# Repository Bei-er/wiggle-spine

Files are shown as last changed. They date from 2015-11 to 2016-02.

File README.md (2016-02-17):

wiggleport

This is the Wiggle **Spine**, an open hardware design for [Wiggleport](http://wiggleport.org)'s power and data hub.

* Each "spine" board has a 480 Mbit/s USB 2.0 uplink and 7 connectors for **modules**.
* Drive up to 14 speakers at 48/96 kHz per channel from one USB port.
* Connect sensors and lights, sync them perfectly with sound and each other.
* Use it to create objects and environments that are perfectly synchronized with immersive sound and vibration.
* Connect other audio-frequency devices like vibration transducers, LED strobes, and modular synthesizers.
* Use all the processing power in your PC, or run from an embedded Linux board like the Raspberry Pi 2.
* Gain accurate control of I/O timing from high-level languages like Javascript.

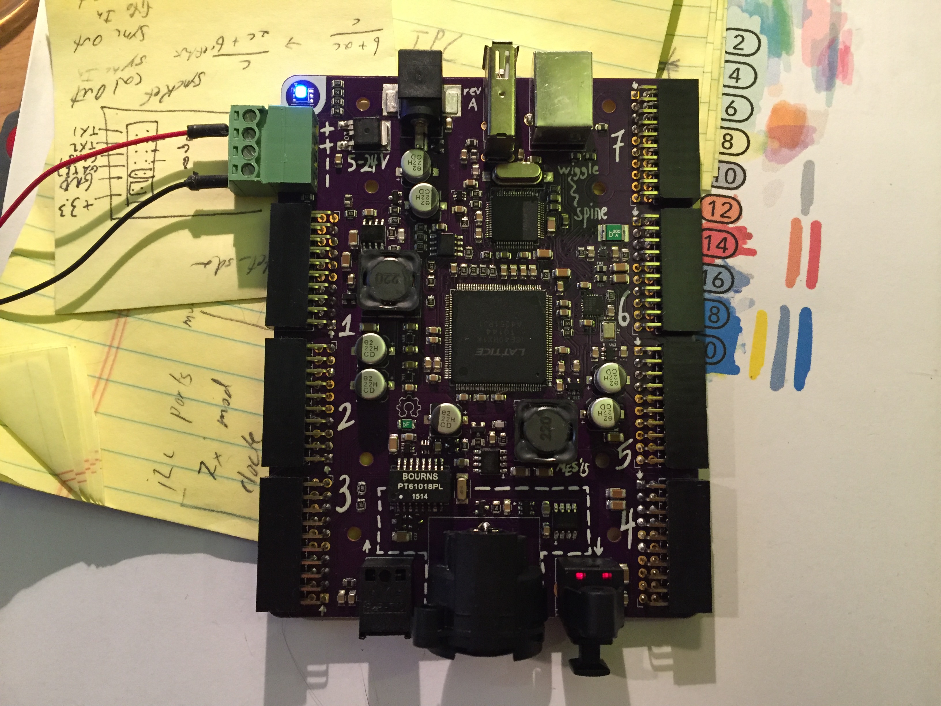
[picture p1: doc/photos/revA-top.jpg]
Wiggle Spine prototype photo


Scale it up or down
-------------------

* Multiple spines can be synchronized with cheap TOSLINK-style optical cables
  * USB links can go to the same or different computers, depending on how much processing power you need
  * Everyone shares a common audio clock and timestamps

* The spine also has a built-in DMX output so it's easy to add inexpensive lights and effects to your project
  * The output has galvanic isolation, to prevent grounding problems or audio hum
  * The DMX outputs can of course synchronize with all other inputs and outputs

* Wiggleport distributes power too, not just data
  * Flexible power input, 5 to 24 volts 
  * Lots of power, over 300 watts total
  * Each module has 5V, 3.3V, and 5-24V available
  * There's also a 5V power output for running a Raspberry Pi or other small computer
  * Also there's a watchdog timer, to reboot the computer if it stops running for any reason

Internals
---------

Wiggleport is an open source hardware design optimized for simple and straightforward real-time performance. It's based around an FTDI FT2232H high-speed USB FIFO interface, combined with a precision clock synthesizer and a tiny FPGA for glue logic. It stays simple and inexpensive by doing much of the work in software, relying on the powerful CPUs available on even small embedded Linux boards now.

Wiggleport isn't really a sound card, even though you can use it as one. It has its own APIs for C++, MIDI, and Javascript. You can write code for precisely timed multichannel sound installations on your laptop on Mac OS, for example, and run the same code on a Raspberry Pi later on.

Going even deeper, Wiggleport is really kind of a construction kit for hardware and drivers that stream signals in real-time. This reconfigurability is what lets Wiggleport automatically configure the various add-on modules, but you can also use this core directly to create your own hardware, with or without including an FPGA.

**Coming soon**... development is happening here now! You can follow the progress at [wiggleport.org](http://wiggleport.org).

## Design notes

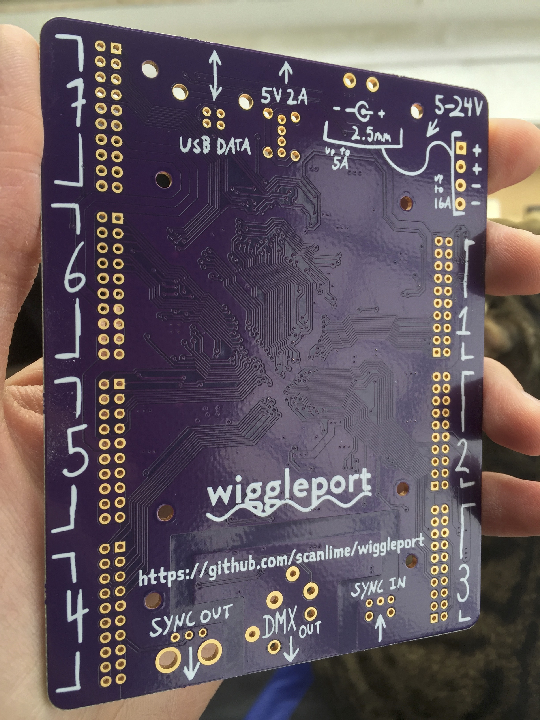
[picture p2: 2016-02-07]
doc/photos/revA-bottom.jpg

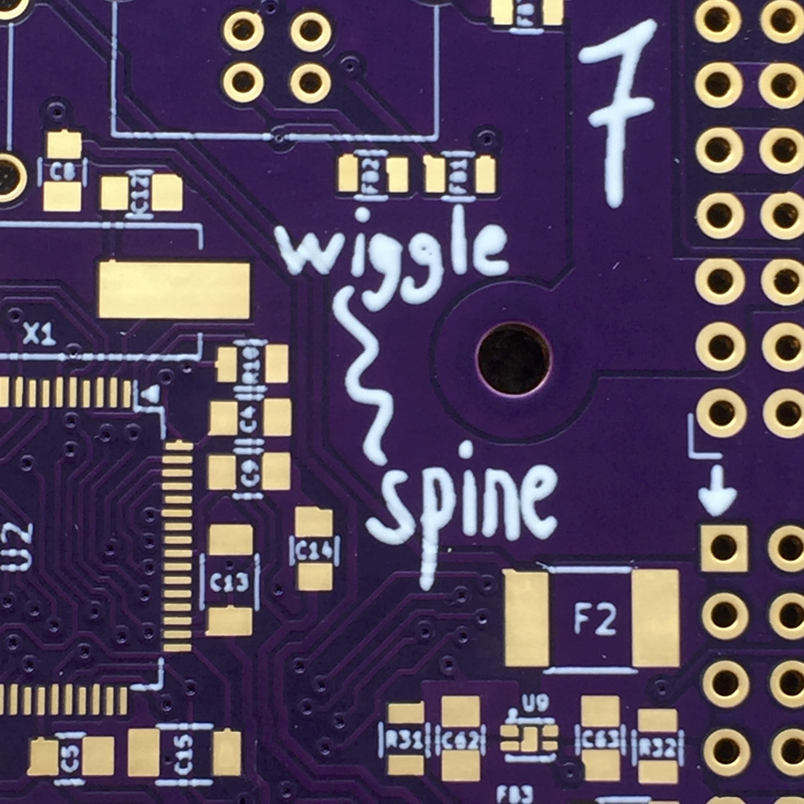
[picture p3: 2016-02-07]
doc/photos/revA-spine-closeup.jpg

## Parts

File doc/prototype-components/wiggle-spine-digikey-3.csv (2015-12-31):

Index | Quantity | Part Number | Description | Customer Reference | Available Quantity | Backorder Quantity | Unit Price USD | Extended Price USD
1 | 50 | 1276-6370-1-ND | FERRITE CHIP 30 OHM 6000MA 0805 |  | 50 | 0 | 0.05640 | 2.82
2 | 10 | 490-7989-1-ND | CAP CER 1000PF 250VAC SL 1808 |  | 10 | 0 | 0.71700 | 7.17
3 | 50 | 493-6180-1-ND | CAP ALUM 22UF 20% 50V SMD |  | 50 | 0 | 0.24320 | 12.16
4 | 10 | 497-3735-1-ND | IC TXRX 5V RS485/422 ESD 8-SOIC |  | 10 | 0 | 0.78700 | 7.87
5 | 25 | 507-1797-1-ND | PTC RESTTBLE 0.20A 30V CHIP 1206 |  | 25 | 0 | 0.09920 | 2.48
6 | 100 | 568-5818-1-ND | MOSFET N-CH 60V 0.36A SOT-23 |  | 100 | 0 | 0.07000 | 7.00
7 | 20 | AP2204K-5.0TRG1DICT-ND | IC REG LDO 5V 0.15A SOT25 |  | 20 | 0 | 0.36300 | 7.26
8 | 20 | BAT54A-FDICT-ND | DIODE ARRAY SCHOTTKY 30V SOT23-3 |  | 20 | 0 | 0.17000 | 3.40
9 | 20 | DMN3190LDW-7DICT-ND | MOSFET 2N-CH 30V 1A SOT363 |  | 20 | 0 | 0.33000 | 6.60

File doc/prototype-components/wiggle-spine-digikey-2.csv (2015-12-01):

Index | Quantity | Part Number | Description | Customer Reference | Available Quantity | Backorder Quantity | Unit Price USD | Extended Price USD
1 | 10 | CLY6D-FKC-CK1N1D1BB7D3D3CT-ND | MSMD LED 3 IN 1 PLCC6 |  | 10 | 0 | 0.49000 | 4.90
2 | 100 | RMCF0805JT750RCT-ND | RES SMD 750 OHM 5% 1/8W 0805 |  | 100 | 0 | 0.00880 | 0.88
3 | 100 | RMCF0805JT240RCT-ND | RES SMD 240 OHM 5% 1/8W 0805 |  | 100 | 0 | 0.00880 | 0.88

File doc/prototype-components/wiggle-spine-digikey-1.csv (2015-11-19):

Index | Quantity | Part Number | Description | Customer Reference | Available Quantity | Backorder Quantity | Unit Price USD | Extended Price USD
1 | 2 | FRDM-KE04Z-ND | DEV TOOL FREEDOM KINETIS 40MHZ |  | 2 | 0 | 15.00000 | 30.00
2 | 1 | 296-36490-ND | EVAL MODULE FOR TAS5760XX |  | 1 | 0 | 100.98000 | 100.98
3 | 25 | 1028-1295-1-ND | IC REG BUCK ADJ 3A SYNC 8SOP |  | 25 | 0 | 0.73000 | 18.25
4 | 10 | 1080-1428-ND | TRANSMITTER FBR OPT IR PHOTOLINK |  | 10 | 0 | 0.86600 | 8.66
5 | 10 | 1080-1433-ND | RECEIVER FIBER OPT IR PHOTOLINK |  | 10 | 0 | 1.64700 | 16.47
6 | 100 | 1276-1829-1-ND | CAP CER 20PF 50V NP0 0805 |  | 100 | 0 | 0.02720 | 2.72
7 | 100 | 1276-6342-1-ND | FERRITE CHIP 26 OHM 2000MA 0805 |  | 100 | 0 | 0.02240 | 2.24
8 | 4 | 220-1565-ND | IC FPGA 96 I/O 144TQFP |  | 4 | 0 | 5.71000 | 22.84
9 | 10 | 296-1275-1-ND | IC DIFF BUS TXCVR 8-SOIC |  | 10 | 0 | 0.68000 | 6.80
10 | 4 | 336-2401-5-ND | IC CLK GENERATOR 160MHZ 20QFN |  | 4 | 0 | 2.69000 | 10.76
11 | 100 | 490-10743-1-ND | CAP CER 1UF 50V X5R 0805 |  | 100 | 0 | 0.08360 | 8.36
12 | 100 | 490-10756-1-ND | CAP CER 10UF 50V X5R 1206 |  | 100 | 0 | 0.15300 | 15.30
13 | 100 | 490-1615-1-ND | CAP CER 100PF 50V NP0 0805 |  | 100 | 0 | 0.03910 | 3.91
14 | 250 | 490-9672-1-ND | CAP CER 0.1UF 50V X7R 0805 |  | 250 | 0 | 0.03760 | 9.40
15 | 100 | 490-9741-1-ND | CAP CER 1000PF 50V X7R 0805 |  | 100 | 0 | 0.02860 | 2.86
16 | 4 | 495-4962-1-ND | CAP FILM 1000PF 20% 1.5KVDC RAD |  | 4 | 0 | 0.88000 | 3.52
17 | 10 | 507-1777-1-ND | PTC RESTTBLE 2.0A 8V CHIP 1812 |  | 10 | 0 | 0.16100 | 1.61
18 | 10 | 553-2272-ND | CONN USB TYPE B JACK |  | 10 | 0 | 0.56000 | 5.60
19 | 10 | 568-6542-1-ND | TVS DIODE 5.5VWM 6TSSOP |  | 10 | 0 | 0.34600 | 3.46
20 | 10 | 644-1267-1-ND | CRYSTAL 25.0000MHZ 8PF SMD |  | 10 | 0 | 0.64100 | 6.41
21 | 5 | 732-5932-1-ND | CONN PWR JACK DC RA SMD |  | 5 | 0 | 1.99000 | 9.95
22 | 4 | 768-1024-1-ND | IC USB HS DUAL UART/FIFO 64-LQFP |  | 4 | 0 | 6.71000 | 26.84
23 | 25 | 785-1351-1-ND | MOSFET P-CH 40V 40A TO252 |  | 25 | 0 | 0.40440 | 10.11
24 | 100 | BAT54C-FDICT-ND | DIODE ARRAY SCHOTTKY 30V SOT23-3 |  | 100 | 0 | 0.09430 | 9.43
25 | 10 | CAT93C56VI-GT3OSCT-ND | IC EEPROM 2KBIT 2MHZ 8SOIC |  | 10 | 0 | 0.39000 | 3.90
26 | 10 | ED2991-ND | CONN USB TYPE A R/A VERTICAL |  | 10 | 0 | 0.64200 | 6.42
27 | 25 | IRFML8244TRPBFCT-ND | MOSFET N-CH 25V 5.8A SOT23 |  | 25 | 0 | 0.18160 | 4.54
28 | 20 | MMBZ12VALT1GOSCT-ND | TVS DIODE 8.5VWM 17VC SOT23 |  | 20 | 0 | 0.18800 | 3.76
29 | 25 | NC7WZ14P6XCT-ND | IC INVERTER DUAL SCHMITT SC70-6 |  | 25 | 0 | 0.23200 | 5.80
30 | 100 | RMCF0805FT12K0CT-ND | RES SMD 12K OHM 1% 1/8W 0805 |  | 100 | 0 | 0.01230 | 1.23
31 | 100 | RMCF0805FT16K0CT-ND | RES SMD 16K OHM 1% 1/8W 0805 |  | 100 | 0 | 0.01230 | 1.23
32 | 100 | RMCF0805FT27K0CT-ND | RES SMD 27K OHM 1% 1/8W 0805 |  | 100 | 0 | 0.01230 | 1.23
33 | 100 | RMCF0805FT5K10CT-ND | RES SMD 5.1K OHM 1% 1/8W 0805 |  | 100 | 0 | 0.01230 | 1.23
34 | 100 | RMCF0805JT100KCT-ND | RES SMD 100K OHM 5% 1/8W 0805 |  | 100 | 0 | 0.00880 | 0.88
35 | 100 | RMCF0805JT10K0CT-ND | RES SMD 10K OHM 5% 1/8W 0805 |  | 100 | 0 | 0.00880 | 0.88
36 | 100 | RMCF0805JT10R0CT-ND | RES SMD 10 OHM 5% 1/8W 0805 |  | 100 | 0 | 0.00880 | 0.88
37 | 100 | RMCF0805JT150RCT-ND | RES SMD 150 OHM 5% 1/8W 0805 |  | 100 | 0 | 0.00880 | 0.88
38 | 100 | RMCF0805JT1M00CT-ND | RES SMD 1M OHM 5% 1/8W 0805 |  | 100 | 0 | 0.00880 | 0.88
39 | 100 | RMCF0805JT2K20CT-ND | RES SMD 2.2K OHM 5% 1/8W 0805 |  | 100 | 0 | 0.00880 | 0.88
40 | 100 | RMCF0805JT4K70CT-ND | RES SMD 4.7K OHM 5% 1/8W 0805 |  | 100 | 0 | 0.00880 | 0.88
41 | 20 | SIP32408DNP-T1-GE4CT-ND | IC LOAD SWITCH 4TDFN |  | 20 | 0 | 0.38700 | 7.74
42 | 25 | SRR1280-220MCT-ND | FIXED IND 22UH 4.3A 38.6 MOHM |  | 25 | 0 | 0.86800 | 21.70
43 | 25 | TCR2EF12LM(CTCT-ND | IC REG LDO 1.2V 0.2A SMV |  | 25 | 0 | 0.21640 | 5.41
44 | 25 | TCR2EF25LM(CTCT-ND | IC REG LDO 2.5V 0.2A SMV |  | 25 | 0 | 0.21640 | 5.41
45 | 10 | 535-9067-1-ND | CRYSTAL 12.0000MHZ 18PF SMD |  | 10 | 0 | 0.23700 | 2.37
 |  |  |  |  |  | Subtotal | 414.61
 |  |  |  |  |  | Shipping | unknown
 |  |  |  |  |  | Estimated Sales Tax | 39.39
 |  |  |  |  |  | Total | unknown

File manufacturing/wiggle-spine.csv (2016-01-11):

Reference | Value | Footprint | Datasheet | Vend1 | Vend1Id | RefPrice1k | Mfg1 | Mfg1Id | Safety Rating | Description
CON1 | USB-B | Connect:USB_B | http://productfinder.pulseeng.com/products/datasheets/E8144-B02022-L.PDF | Digikey | 553-2272-ND | 0.28 | Pulse | E8144-B02022-L
FB2 | Ferrite bead | Resistors_SMD:R_0805 | http://www.samsungsem.com/kr/front/downloadcms.do?fileName=S_CIS21J121NE.pdf | Digikey | 1276-6370-1-ND | 0.02383 | Samsung | CIS21P300NE
FB1 | Ferrite bead | Resistors_SMD:R_0805 | http://www.samsungsem.com/kr/front/downloadcms.do?fileName=S_CIS21J121NE.pdf | Digikey | 1276-6370-1-ND | 0.02383 | Samsung | CIS21P300NE
R4 | 4.7k | Resistors_SMD:R_0805 | https://www.seielect.com/Catalog/SEI-RMCF_RMCP.pdf | Digikey | RMCF0805JT4K70CT-ND | 0.0032 | Stackpole | RMCF0805JT4K70
R5 | 10k | Resistors_SMD:R_0805 | http://www.seielect.com/Catalog/SEI-RMCF_RMCP.pdf | Digikey | RMCF0805JT10K0CT-ND | 0.0032 | Stackpole | RMCF0805JT10K0
U2 | FT2232H | Housings_QFP:LQFP-64_10x10mm_Pitch0.5mm | http://www.ftdichip.com/Support/Documents/DataSheets/ICs/DS_FT2232H.pdf | Digikey | 768-1024-1-ND | 3.70 | FTDI | FT2232HL-REEL
R10 | 12k 1% | Resistors_SMD:R_0805 | https://www.seielect.com/Catalog/SEI-RMCF_RMCP.pdf | Digikey | RMCF0805FT12K0TR-ND | 0.0032 | Stackpole | RMCF0805FT12K0
R7 | 4.7k | Resistors_SMD:R_0805 | https://www.seielect.com/Catalog/SEI-RMCF_RMCP.pdf | Digikey | RMCF0805JT4K70CT-ND | 0.0032 | Stackpole | RMCF0805JT4K70
D1 | TVS DIODE 5.5VWM | TO_SOT_Packages_SMD:SC-70-6 | http://www.nxp.com/documents/data_sheet/PRTR5V0U4Y.pdf | Digikey | DRTR5V0U4S-7DICT-ND | 0.12266 | Diodes Inc | DRTR5V0U4S-7
FB3 | Ferrite bead | Resistors_SMD:R_0805 | http://www.samsungsem.com/kr/front/downloadcms.do?fileName=S_CIS21J121NE.pdf | Digikey | 1276-6370-1-ND | 0.02383 | Samsung | CIS21P300NE
U1 | 93C56 | Housings_SOIC:SOIC-8_3.9x4.9mm_Pitch1.27mm | http://www.onsemi.com/pub_link/Collateral/CAT93C56-D.PDF | Digikey | CAT93C56VI-GT3OSCT-ND | 0.14893 | ON Semi | CAT93C56VI-GT3
R1 | 10k | Resistors_SMD:R_0805 | http://www.seielect.com/Catalog/SEI-RMCF_RMCP.pdf | Digikey | RMCF0805JT10K0CT-ND | 0.0032 | Stackpole | RMCF0805JT10K0
R2 | 10k | Resistors_SMD:R_0805 | http://www.seielect.com/Catalog/SEI-RMCF_RMCP.pdf | Digikey | RMCF0805JT10K0CT-ND | 0.0032 | Stackpole | RMCF0805JT10K0
R3 | 10k | Resistors_SMD:R_0805 | http://www.seielect.com/Catalog/SEI-RMCF_RMCP.pdf | Digikey | RMCF0805JT10K0CT-ND | 0.0032 | Stackpole | RMCF0805JT10K0
R6 | 2.2k | Resistors_SMD:R_0805 | http://www.seielect.com/Catalog/SEI-RMCF_RMCP.pdf | Digikey | RMCF0805JT2K20CT-ND | 0.0032 | Stackpole | RMCF0805JT2K20CT
C2 | 0.1uF | Capacitors_SMD:C_0805 | http://psearch.murata.com/capacitor/product/GRM21BR71H104MA01%23.pdf | Digikey | 490-9672-2-ND | 0.01880 | Murata | GRM21BR71H104MA01L
X1 | 12 MHz | Crystals:Crystal_HC49-SD_SMD | http://www.abracon.com/Resonators/abls.pdf | Digikey | 535-10218-1-ND | 0.172 | Abracon | ABLS-12.000MHZ-B4-T
C12 | 20pF | Capacitors_SMD:C_0805 | http://www.samsungsem.com/kr/support/product-search/mlcc/CL21C200JBANNNC.jsp | Digikey | 1276-1829-1-ND | 0.01485 | Samsung | CL21C200JBANNNC
R8 | 10 | Resistors_SMD:R_0805 | http://www.seielect.com/Catalog/SEI-RMCF_RMCP.pdf | Digikey | RMCF0805JT10R0CT-ND | 0.0032 | Stackpole | RMCF0805JT10R0CT
R9 | 10 | Resistors_SMD:R_0805 | http://www.seielect.com/Catalog/SEI-RMCF_RMCP.pdf | Digikey | RMCF0805JT10R0CT-ND | 0.0032 | Stackpole | RMCF0805JT10R0CT
C3 | 0.1uF | Capacitors_SMD:C_0805 | http://psearch.murata.com/capacitor/product/GRM21BR71H104MA01%23.pdf | Digikey | 490-9672-2-ND | 0.01880 | Murata | GRM21BR71H104MA01L
C4 | 0.1uF | Capacitors_SMD:C_0805 | http://psearch.murata.com/capacitor/product/GRM21BR71H104MA01%23.pdf | Digikey | 490-9672-2-ND | 0.01880 | Murata | GRM21BR71H104MA01L
C5 | 0.1uF | Capacitors_SMD:C_0805 | http://psearch.murata.com/capacitor/product/GRM21BR71H104MA01%23.pdf | Digikey | 490-9672-2-ND | 0.01880 | Murata | GRM21BR71H104MA01L
C7 | 0.1uF | Capacitors_SMD:C_0805 | http://psearch.murata.com/capacitor/product/GRM21BR71H104MA01%23.pdf | Digikey | 490-9672-2-ND | 0.01880 | Murata | GRM21BR71H104MA01L
C9 | 0.1uF | Capacitors_SMD:C_0805 | http://psearch.murata.com/capacitor/product/GRM21BR71H104MA01%23.pdf | Digikey | 490-9672-2-ND | 0.01880 | Murata | GRM21BR71H104MA01L
C11 | 0.1uF | Capacitors_SMD:C_0805 | http://psearch.murata.com/capacitor/product/GRM21BR71H104MA01%23.pdf | Digikey | 490-9672-2-ND | 0.01880 | Murata | GRM21BR71H104MA01L
C6 | 0.1uF | Capacitors_SMD:C_0805 | http://psearch.murata.com/capacitor/product/GRM21BR71H104MA01%23.pdf | Digikey | 490-9672-2-ND | 0.01880 | Murata | GRM21BR71H104MA01L
C1 | 0.1uF | Capacitors_SMD:C_0805 | http://psearch.murata.com/capacitor/product/GRM21BR71H104MA01%23.pdf | Digikey | 490-9672-2-ND | 0.01880 | Murata | GRM21BR71H104MA01L
C13 | 10uF | Capacitors_SMD:C_1206 | http://www.murata.com/~/media/webrenewal/support/library/catalog/products/capacitor/mlcc/c02e.ashx | Digikey | 490-10756-2-ND | 0.07429 | Murata | GRM31CR61H106MA12L
C15 | 10uF | Capacitors_SMD:C_1206 | http://www.murata.com/~/media/webrenewal/support/library/catalog/products/capacitor/mlcc/c02e.ashx | Digikey | 490-10756-2-ND | 0.07429 | Murata | GRM31CR61H106MA12L
C8 | 0.1uF | Capacitors_SMD:C_0805 | http://psearch.murata.com/capacitor/product/GRM21BR71H104MA01%23.pdf | Digikey | 490-9672-2-ND | 0.01880 | Murata | GRM21BR71H104MA01L
C10 | 10uF | Capacitors_SMD:C_1206 | http://www.murata.com/~/media/webrenewal/support/library/catalog/products/capacitor/mlcc/c02e.ashx | Digikey | 490-10756-2-ND | 0.07429 | Murata | GRM31CR61H106MA12L
FB4 | Ferrite bead | Resistors_SMD:R_0805 | http://www.samsungsem.com/kr/front/downloadcms.do?fileName=S_CIS21J121NE.pdf | Digikey | 1276-6370-1-ND | 0.02383 | Samsung | CIS21P300NE
C14 | 0.1uF | Capacitors_SMD:C_0805 | http://psearch.murata.com/capacitor/product/GRM21BR71H104MA01%23.pdf | Digikey | 490-9672-2-ND | 0.01880 | Murata | GRM21BR71H104MA01L
C17 | 10uF | Capacitors_SMD:C_1206 | http://www.murata.com/~/media/webrenewal/support/library/catalog/products/capacitor/mlcc/c02e.ashx | Digikey | 490-10756-2-ND | 0.07429 | Murata | GRM31CR61H106MA12L
C16 | 20pF | Capacitors_SMD:C_0805 | http://www.samsungsem.com/kr/support/product-search/mlcc/CL21C200JBANNNC.jsp | Digikey | 1276-1829-1-ND | 0.01485 | Samsung | CL21C200JBANNNC
T1 | 10/100baseT transformer | Housings_SOIC:SOIC-16_7.5x10.3mm_Pitch1.27mm | http://www.mouser.com/ds/2/54/PT61018PEL-336005.pdf | Mouser | 652-PT61018PEL | 0.78 | Bourns | PT61018PEL
C23 | 1nF | Capacitors_SMD:C_0805 | http://search.murata.co.jp/Ceramy/image/img/A01X/G101/ENG/GRM216R71H102KA01-01.pdf | Digikey | 490-9741-1-ND | 0.0156 | Murata | GRM216R71H102KA01D
D2 | BAT54 2x common cathode | TO_SOT_Packages_SMD:SOT-23 | http://www.diodes.com/_files/datasheets/ds11005.pdf | Digikey | BAT54C-FDICT-ND | .03955 | Diodes Inc | BAT54C-7-F
U3 | NC7WZ14 | TO_SOT_Packages_SMD:SC-70-6 | http://www.fairchildsemi.com/datasheets/NC/NC7WZ14.pdf | Digikey | NC7WZ14P6XCT-ND | 0.07631 | Fairchild | NC7WZ14P6X
R13 | 240 | Resistors_SMD:R_0805 | https://www.seielect.com/Catalog/SEI-RMCF_RMCP.pdf | Digikey | RMCF0805JT240RCT-ND | 0.0032 | Stackpole | RMCF0805JT240R
C22 | 10uF | Capacitors_SMD:C_1206 | http://www.murata.com/~/media/webrenewal/support/library/catalog/products/capacitor/mlcc/c02e.ashx | Digikey | 490-10756-2-ND | 0.07429 | Murata | GRM31CR61H106MA12L
C20 | 10uF | Capacitors_SMD:C_1206 | http://www.murata.com/~/media/webrenewal/support/library/catalog/products/capacitor/mlcc/c02e.ashx | Digikey | 490-10756-2-ND | 0.07429 | Murata | GRM31CR61H106MA12L
C18 | 0.1uF | Capacitors_SMD:C_0805 | http://psearch.murata.com/capacitor/product/GRM21BR71H104MA01%23.pdf | Digikey | 490-9672-2-ND | 0.01880 | Murata | GRM21BR71H104MA01L
D4 | BAT54 2x common cathode | TO_SOT_Packages_SMD:SOT-23 | http://www.diodes.com/_files/datasheets/ds11005.pdf | Digikey | BAT54C-FDICT-ND | .03955 | Diodes Inc | BAT54C-7-F
C21 | 1nF | Capacitors_SMD:C_1808 | http://psearch.murata.com/capacitor/product/GA342DR7GF102KW02%23.pdf | Digikey | 490-7989-1-ND | 0.24075 | Murata | GA342DR7GF102KW02L | Y2 Safety Rated
F1 | 200mA PTC | Resistors_SMD:R_1206 | http://www.belfuse.com/pdfs/0ZCJ.pdf | Digikey | 507-1797-1-ND | 0.06269 | Bel Fuse | 0ZCJ0020FF2E
CON2 | XLR-3 Female | Connect:XLR3MC | http://www.neutrik.us/en-us/xlr/aa-series/nc3faah2-0 | Mouser | 568-NC3FAAH-2-O | 0.653 | Neutrik | NC3FAAH2-0
U5 | ST485E | Housings_SOIC:SOIC-8_3.9x4.9mm_Pitch1.27mm | http://www.st.com/web/en/resource/technical/document/datasheet/CD00002703.pdf | Digikey | 497-3735-1-ND | 0.40145 | STMicroelectronics | ST485ECDR
D3 | BAT54 2x common anode | TO_SOT_Packages_SMD:SOT-23 | http://www.diodes.com/_files/datasheets/ds11005.pdf | Digikey | BAT54A-FDICT-ND | .03893 | Diodes Inc | BAT54A-7-F
U4 | AP2204K-5.0 | TO_SOT_Packages_SMD:SOT-23-5 | http://www.diodes.com/_files/datasheets/AP2204.pdf | Digikey | AP2204K-5.0TRG1DICT-ND | 0.13857 | Diodes Inc | AP2204K-5.0TRG1
C24 | 1uF | Capacitors_SMD:C_0805 | http://www.murata.com/~/media/webrenewal/support/library/catalog/products/capacitor/mlcc/c02e.ashx | Digikey | 490-10743-2-ND | 0.03980 | Murata | GRM219R61H105KA73D
C19 | 1nF | Capacitors_SMD:C_0805 | http://search.murata.co.jp/Ceramy/image/img/A01X/G101/ENG/GRM216R71H102KA01-01.pdf | Digikey | 490-9741-1-ND | 0.0156 | Murata | GRM216R71H102KA01D
R12 | 10k | Resistors_SMD:R_0805 | https://www.seielect.com/Catalog/SEI-RMCF_RMCP.pdf | Digikey | RMCF0805JT10K0CT-ND | 0.0032 | Stackpole | RMCF0805JT10K0
R11 | 10k | Resistors_SMD:R_0805 | https://www.seielect.com/Catalog/SEI-RMCF_RMCP.pdf | Digikey | RMCF0805JT10K0CT-ND | 0.0032 | Stackpole | RMCF0805JT10K0
Q1 | DMN3190LDW | TO_SOT_Packages_SMD:SC-70-6 | http://www.diodes.com/_files/datasheets/DMN3190LDW.pdf | Digikey | DMN3190LDW-7DICT-ND | 0.09480 | Diodes Inc | DMN3190LDW-7
C85 | 0.1uF | Capacitors_SMD:C_0805 | http://psearch.murata.com/capacitor/product/GRM21BR71H104MA01%23.pdf | Digikey | 490-9672-2-ND | 0.01880 | Murata | GRM21BR71H104MA01L
MOD1 | 2.54mm 2x10 right angle female header | Socket_Strips:Socket_Strip_Angled_2x10_Mirror | http://www.centronic.url.tw/pf/p29.pdf | eBay | http://www.ebay.com/itm/20pcs-2-54mm-pitch-2x10Pin-Header-Right-Angle-Female-Double-Row-Socket-Connector-/271560108036 | 0.275 | Centronic | 230-20
MOD2 | 2.54mm 2x10 right angle female header | Socket_Strips:Socket_Strip_Angled_2x10_Mirror | http://www.centronic.url.tw/pf/p29.pdf | eBay | http://www.ebay.com/itm/20pcs-2-54mm-pitch-2x10Pin-Header-Right-Angle-Female-Double-Row-Socket-Connector-/271560108036 | 0.275 | Centronic | 230-20
MOD3 | 2.54mm 2x10 right angle female header | Socket_Strips:Socket_Strip_Angled_2x10_Mirror | http://www.centronic.url.tw/pf/p29.pdf | eBay | http://www.ebay.com/itm/20pcs-2-54mm-pitch-2x10Pin-Header-Right-Angle-Female-Double-Row-Socket-Connector-/271560108036 | 0.275 | Centronic | 230-20
MOD4 | 2.54mm 2x10 right angle female header | Socket_Strips:Socket_Strip_Angled_2x10_Mirror | http://www.centronic.url.tw/pf/p29.pdf | eBay | http://www.ebay.com/itm/20pcs-2-54mm-pitch-2x10Pin-Header-Right-Angle-Female-Double-Row-Socket-Connector-/271560108036 | 0.275 | Centronic | 230-20
MOD5 | 2.54mm 2x10 right angle female header | Socket_Strips:Socket_Strip_Angled_2x10_Mirror | http://www.centronic.url.tw/pf/p29.pdf | eBay | http://www.ebay.com/itm/20pcs-2-54mm-pitch-2x10Pin-Header-Right-Angle-Female-Double-Row-Socket-Connector-/271560108036 | 0.275 | Centronic | 230-20
MOD6 | 2.54mm 2x10 right angle female header | Socket_Strips:Socket_Strip_Angled_2x10_Mirror | http://www.centronic.url.tw/pf/p29.pdf | eBay | http://www.ebay.com/itm/20pcs-2-54mm-pitch-2x10Pin-Header-Right-Angle-Female-Double-Row-Socket-Connector-/271560108036 | 0.275 | Centronic | 230-20
MOD7 | 2.54mm 2x10 right angle female header | Socket_Strips:Socket_Strip_Angled_2x10_Mirror | http://www.centronic.url.tw/pf/p29.pdf | eBay | http://www.ebay.com/itm/20pcs-2-54mm-pitch-2x10Pin-Header-Right-Angle-Female-Double-Row-Socket-Connector-/271560108036 | 0.275 | Centronic | 230-20
U6 | iCE40-HX1K-TQ144 | Housings_QFP:TQFP-144_20x20mm_Pitch0.5mm | http://www.latticesemi.com/~/media/LatticeSemi/Documents/DataSheets/iCE/iCE40LPHXFamilyDataSheet.pdf | Digikey | 220-1565-ND | 4.5703 | Lattice | ICE40HX1K-TQ144
R15 | 10k | Resistors_SMD:R_0805 | http://www.seielect.com/Catalog/SEI-RMCF_RMCP.pdf | Digikey | RMCF0805JT10K0CT-ND | 0.0032 | Stackpole | RMCF0805JT10K0
R14 | 150 | Resistors_SMD:R_0805 | https://www.seielect.com/Catalog/SEI-RMCF_RMCP.pdf | Digikey | RMCF0805JT150RCT-ND | 0.0032 | Stackpole | RMCF0805JT150R
R16 | 10k | Resistors_SMD:R_0805 | http://www.seielect.com/Catalog/SEI-RMCF_RMCP.pdf | Digikey | RMCF0805JT10K0CT-ND | 0.0032 | Stackpole | RMCF0805JT10K0
R22 | 10k | Resistors_SMD:R_0805 | http://www.seielect.com/Catalog/SEI-RMCF_RMCP.pdf | Digikey | RMCF0805JT10K0CT-ND | 0.0032 | Stackpole | RMCF0805JT10K0
R21 | 10k | Resistors_SMD:R_0805 | http://www.seielect.com/Catalog/SEI-RMCF_RMCP.pdf | Digikey | RMCF0805JT10K0CT-ND | 0.0032 | Stackpole | RMCF0805JT10K0
C26 | 0.1uF | Capacitors_SMD:C_0805 | http://psearch.murata.com/capacitor/product/GRM21BR71H104MA01%23.pdf | Digikey | 490-9672-2-ND | 0.01880 | Murata | GRM21BR71H104MA01L
C28 | 10uF | Capacitors_SMD:C_1206 | http://www.murata.com/~/media/webrenewal/support/library/catalog/products/capacitor/mlcc/c02e.ashx | Digikey | 490-10756-2-ND | 0.07429 | Murata | GRM31CR61H106MA12L
C30 | 0.1uF | Capacitors_SMD:C_0805 | http://psearch.murata.com/capacitor/product/GRM21BR71H104MA01%23.pdf | Digikey | 490-9672-2-ND | 0.01880 | Murata | GRM21BR71H104MA01L
C32 | 0.1uF | Capacitors_SMD:C_0805 | http://psearch.murata.com/capacitor/product/GRM21BR71H104MA01%23.pdf | Digikey | 490-9672-2-ND | 0.01880 | Murata | GRM21BR71H104MA01L
C34 | 0.1uF | Capacitors_SMD:C_0805 | http://psearch.murata.com/capacitor/product/GRM21BR71H104MA01%23.pdf | Digikey | 490-9672-2-ND | 0.01880 | Murata | GRM21BR71H104MA01L
C36 | 0.1uF | Capacitors_SMD:C_0805 | http://psearch.murata.com/capacitor/product/GRM21BR71H104MA01%23.pdf | Digikey | 490-9672-2-ND | 0.01880 | Murata | GRM21BR71H104MA01L
C37 | 0.1uF | Capacitors_SMD:C_0805 | http://psearch.murata.com/capacitor/product/GRM21BR71H104MA01%23.pdf | Digikey | 490-9672-2-ND | 0.01880 | Murata | GRM21BR71H104MA01L
C39 | 0.1uF | Capacitors_SMD:C_0805 | http://psearch.murata.com/capacitor/product/GRM21BR71H104MA01%23.pdf | Digikey | 490-9672-2-ND | 0.01880 | Murata | GRM21BR71H104MA01L
C40 | 0.1uF | Capacitors_SMD:C_0805 | http://psearch.murata.com/capacitor/product/GRM21BR71H104MA01%23.pdf | Digikey | 490-9672-2-ND | 0.01880 | Murata | GRM21BR71H104MA01L
C41 | 0.1uF | Capacitors_SMD:C_0805 | http://psearch.murata.com/capacitor/product/GRM21BR71H104MA01%23.pdf | Digikey | 490-9672-2-ND | 0.01880 | Murata | GRM21BR71H104MA01L
C42 | 0.1uF | Capacitors_SMD:C_0805 | http://psearch.murata.com/capacitor/product/GRM21BR71H104MA01%23.pdf | Digikey | 490-9672-2-ND | 0.01880 | Murata | GRM21BR71H104MA01L
C35 | 0.1uF | Capacitors_SMD:C_0805 | http://psearch.murata.com/capacitor/product/GRM21BR71H104MA01%23.pdf | Digikey | 490-9672-2-ND | 0.01880 | Murata | GRM21BR71H104MA01L
C33 | 0.1uF | Capacitors_SMD:C_0805 | http://psearch.murata.com/capacitor/product/GRM21BR71H104MA01%23.pdf | Digikey | 490-9672-2-ND | 0.01880 | Murata | GRM21BR71H104MA01L
C31 | 0.1uF | Capacitors_SMD:C_0805 | http://psearch.murata.com/capacitor/product/GRM21BR71H104MA01%23.pdf | Digikey | 490-9672-2-ND | 0.01880 | Murata | GRM21BR71H104MA01L
C29 | 0.1uF | Capacitors_SMD:C_0805 | http://psearch.murata.com/capacitor/product/GRM21BR71H104MA01%23.pdf | Digikey | 490-9672-2-ND | 0.01880 | Murata | GRM21BR71H104MA01L
C25 | 0.1uF | Capacitors_SMD:C_0805 | http://psearch.murata.com/capacitor/product/GRM21BR71H104MA01%23.pdf | Digikey | 490-9672-2-ND | 0.01880 | Murata | GRM21BR71H104MA01L
C27 | 0.1uF | Capacitors_SMD:C_0805 | http://psearch.murata.com/capacitor/product/GRM21BR71H104MA01%23.pdf | Digikey | 490-9672-2-ND | 0.01880 | Murata | GRM21BR71H104MA01L
C38 | 0.1uF | Capacitors_SMD:C_0805 | http://psearch.murata.com/capacitor/product/GRM21BR71H104MA01%23.pdf | Digikey | 490-9672-2-ND | 0.01880 | Murata | GRM21BR71H104MA01L
D5 | LED_BGR | LEDs:LED_RGB_PLLC-6 | http://www.cree.com/sitecore%20modules/web/~/media/Files/Cree/LED%20Components%20and%20Modules/HB/Data%20Sheets/1321%20CLY6D%20FKC.pdf | Digikey | CLY6D-FKC-CK1N1D1BB7D3D3CT-ND | 0.35720 | Cree | CLY6D-FKC-CK1N1D1BB7D3D3
R17 | 750 | Resistors_SMD:R_0805 | https://www.seielect.com/Catalog/SEI-RMCF_RMCP.pdf | Digikey | RMCF0805JT750RCT-ND | 0.0032 | Stackpole | RMCF0805JT750R
R19 | 240 | Resistors_SMD:R_0805 | https://www.seielect.com/Catalog/SEI-RMCF_RMCP.pdf | Digikey | RMCF0805JT240RCT-ND | 0.0032 | Stackpole | RMCF0805JT240R
R18 | 750 | Resistors_SMD:R_0805 | https://www.seielect.com/Catalog/SEI-RMCF_RMCP.pdf | Digikey | RMCF0805JT750RCT-ND | 0.0032 | Stackpole | RMCF0805JT750R
R20 | 16k 1% | Resistors_SMD:R_0805 | https://www.seielect.com/Catalog/SEI-RMCF_RMCP.pdf | Digikey | RMCF0805FT16K0CT-ND | 0.00448 | Stackpole | RMCF0805FT16K0
R23 | 100k | Resistors_SMD:R_0805 | https://www.seielect.com/Catalog/SEI-RMCF_RMCP.pdf | Digikey | RMCF0805JT100KCT-ND | 0.00320 | Stackpole | RMCF0805JT100K
C47 | 1uF | Capacitors_SMD:C_0805 | http://www.murata.com/~/media/webrenewal/support/library/catalog/products/capacitor/mlcc/c02e.ashx | Digikey | 490-10743-2-ND | 0.03980 | Murata | GRM219R61H105KA73D
U7 | RT8299A | Housings_SOIC:SOIC-8-1EP_3.9x4.9mm_Pitch1.27mm | http://www.richtek.com/assets/product_file/RT8299A/DS8299A-03.pdf | Digikey | 1028-1295-1-ND | 0.37752 | Richtek | RT8299AZSP
C48 | 0.1uF | Capacitors_SMD:C_0805 | http://psearch.murata.com/capacitor/product/GRM21BR71H104MA01%23.pdf | Digikey | 490-9672-2-ND | 0.01880 | Murata | GRM21BR71H104MA01L
L1 | 22uH | Inductors_NEOSID:Neosid_Inductor_SM-NE127 | http://www.bourns.com/docs/Product-Datasheets/SRR1280.pdf | Digikey | SRR1280-220MTR-ND | 0.42160 | Bourns | SRR1280-220M
R24 | 150 | Resistors_SMD:R_0805 | https://www.seielect.com/Catalog/SEI-RMCF_RMCP.pdf | Digikey | RMCF0805JT150RCT-ND | 0.0032 | Stackpole | RMCF0805JT150R
C49 | 100pF | Capacitors_SMD:C_0805 | http://psearch.murata.com/capacitor/product/GRM21BR71H104MA01%23.pdf | Digikey | 490-1615-1-ND | 0.02130 | Murata | GRM2165C1H101JA01D
R26 | 5.1k 1% | Resistors_SMD:R_0805 | https://www.seielect.com/Catalog/SEI-RMCF_RMCP.pdf | Digikey | RMCF0805FT5K10CT-ND | 0.00448 | Stackpole | RMCF0805FT5K10
R25 | 27k 1% | Resistors_SMD:R_0805 | https://www.seielect.com/Catalog/SEI-RMCF_RMCP.pdf | Digikey | RMCF0805FT27K0CT-ND | 0.00448 | Stackpole | RMCF0805FT27K0
R27 | 100k | Resistors_SMD:R_0805 | https://www.seielect.com/Catalog/SEI-RMCF_RMCP.pdf | Digikey | RMCF0805JT100KCT-ND | 0.00320 | Stackpole | RMCF0805JT100K
D6 | BAT54 2x common cathode | TO_SOT_Packages_SMD:SOT-23 | http://www.diodes.com/_files/datasheets/ds11005.pdf | Digikey | BAT54C-FDICT-ND | .03955 | Diodes Inc | BAT54C-7-F
C50 | 22uF | Capacitors_SMD:c_elec_6.3x7.7 | http://nichicon-us.com/english/products/pdfs/e-cd.pdf | Digikey | 493-6180-2-ND | 0.10868 | Nichicon | UCD1H220MCL1GS
C51 | 22uF | Capacitors_SMD:c_elec_6.3x7.7 | http://nichicon-us.com/english/products/pdfs/e-cd.pdf | Digikey | 493-6180-2-ND | 0.10868 | Nichicon | UCD1H220MCL1GS
C52 | 10uF | Capacitors_SMD:C_1206 | http://www.murata.com/~/media/webrenewal/support/library/catalog/products/capacitor/mlcc/c02e.ashx | Digikey | 490-10756-2-ND | 0.07429 | Murata | GRM31CR61H106MA12L
C43 | 22uF | Capacitors_SMD:c_elec_6.3x7.7 | http://nichicon-us.com/english/products/pdfs/e-cd.pdf | Digikey | 493-6180-2-ND | 0.10868 | Nichicon | UCD1H220MCL1GS
C44 | 22uF | Capacitors_SMD:c_elec_6.3x7.7 | http://nichicon-us.com/english/products/pdfs/e-cd.pdf | Digikey | 493-6180-2-ND | 0.10868 | Nichicon | UCD1H220MCL1GS
C46 | 10uF | Capacitors_SMD:C_1206 | http://www.murata.com/~/media/webrenewal/support/library/catalog/products/capacitor/mlcc/c02e.ashx | Digikey | 490-10756-2-ND | 0.07429 | Murata | GRM31CR61H106MA12L
C45 | 10uF | Capacitors_SMD:C_1206 | http://www.murata.com/~/media/webrenewal/support/library/catalog/products/capacitor/mlcc/c02e.ashx | Digikey | 490-10756-2-ND | 0.07429 | Murata | GRM31CR61H106MA12L
C56 | 1uF | Capacitors_SMD:C_0805 | http://www.murata.com/~/media/webrenewal/support/library/catalog/products/capacitor/mlcc/c02e.ashx | Digikey | 490-10743-2-ND | 0.03980 | Murata | GRM219R61H105KA73D
U8 | RT8299A | Housings_SOIC:SOIC-8-1EP_3.9x4.9mm_Pitch1.27mm | http://www.richtek.com/assets/product_file/RT8299A/DS8299A-03.pdf | Digikey | 1028-1295-1-ND | 0.37752 | Richtek | RT8299AZSP
C57 | 0.1uF | Capacitors_SMD:C_0805 | http://psearch.murata.com/capacitor/product/GRM21BR71H104MA01%23.pdf | Digikey | 490-9672-2-ND | 0.01880 | Murata | GRM21BR71H104MA01L
L2 | 22uH | Inductors_NEOSID:Neosid_Inductor_SM-NE127 | http://www.bourns.com/docs/Product-Datasheets/SRR1280.pdf | Digikey | SRR1280-220MTR-ND | 0.42160 | Bourns | SRR1280-220M
R28 | 150 | Resistors_SMD:R_0805 | https://www.seielect.com/Catalog/SEI-RMCF_RMCP.pdf | Digikey | RMCF0805JT150RCT-ND | 0.0032 | Stackpole | RMCF0805JT150R
C58 | 100pF | Capacitors_SMD:C_0805 | http://psearch.murata.com/capacitor/product/GRM21BR71H104MA01%23.pdf | Digikey | 490-1615-1-ND | 0.02130 | Murata | GRM2165C1H101JA01D
R30 | 5.1k 1% | Resistors_SMD:R_0805 | https://www.seielect.com/Catalog/SEI-RMCF_RMCP.pdf | Digikey | RMCF0805FT5K10CT-ND | 0.00448 | Stackpole | RMCF0805FT5K10
R29 | 16k 1% | Resistors_SMD:R_0805 | https://www.seielect.com/Catalog/SEI-RMCF_RMCP.pdf | Digikey | RMCF0805FT16K0CT-ND | 0.00448 | Stackpole | RMCF0805FT16K0
D7 | BAT54 2x common cathode | TO_SOT_Packages_SMD:SOT-23 | http://www.diodes.com/_files/datasheets/ds11005.pdf | Digikey | BAT54C-FDICT-ND | .03955 | Diodes Inc | BAT54C-7-F
C53 | 22uF | Capacitors_SMD:c_elec_6.3x7.7 | http://nichicon-us.com/english/products/pdfs/e-cd.pdf | Digikey | 493-6180-2-ND | 0.10868 | Nichicon | UCD1H220MCL1GS
C55 | 10uF | Capacitors_SMD:C_1206 | http://www.murata.com/~/media/webrenewal/support/library/catalog/products/capacitor/mlcc/c02e.ashx | Digikey | 490-10756-2-ND | 0.07429 | Murata | GRM31CR61H106MA12L
C54 | 10uF | Capacitors_SMD:C_1206 | http://www.murata.com/~/media/webrenewal/support/library/catalog/products/capacitor/mlcc/c02e.ashx | Digikey | 490-10756-2-ND | 0.07429 | Murata | GRM31CR61H106MA12L
C59 | 22uF | Capacitors_SMD:c_elec_6.3x7.7 | http://nichicon-us.com/english/products/pdfs/e-cd.pdf | Digikey | 493-6180-2-ND | 0.10868 | Nichicon | UCD1H220MCL1GS
C60 | 22uF | Capacitors_SMD:c_elec_6.3x7.7 | http://nichicon-us.com/english/products/pdfs/e-cd.pdf | Digikey | 493-6180-2-ND | 0.10868 | Nichicon | UCD1H220MCL1GS
C61 | 10uF | Capacitors_SMD:C_1206 | http://www.murata.com/~/media/webrenewal/support/library/catalog/products/capacitor/mlcc/c02e.ashx | Digikey | 490-10756-2-ND | 0.07429 | Murata | GRM31CR61H106MA12L
U9 | SiP32408 | TDFN4:TDFN4 | http://www.vishay.com/docs/63717/sip32408.pdf | Digikey | SIP32408DNP-T1-GE4CT-ND | 0.175 | Vishay | SIP32408DNP-T1-GE4
R31 | 100k | Resistors_SMD:R_0805 | https://www.seielect.com/Catalog/SEI-RMCF_RMCP.pdf | Digikey | RMCF0805JT100KCT-ND | 0.00320 | Stackpole | RMCF0805JT100K
CON3 | USB-A | Connect:USB_A_Vertical | http://www.on-shore.com/sites/default/files/manuals/usb-a1ssxx.pdf | Digikey | ED2991-ND | 0.35310 | On-Shore Tech | USB-A1SSW6
FB5 | Ferrite bead | Resistors_SMD:R_0805 | http://www.samsungsem.com/kr/front/downloadcms.do?fileName=S_CIS21J121NE.pdf | Digikey | 1276-6370-1-ND | 0.02383 | Samsung | CIS21P300NE
C63 | 0.1uF | Capacitors_SMD:C_0805 | http://psearch.murata.com/capacitor/product/GRM21BR71H104MA01%23.pdf | Digikey | 490-9672-2-ND | 0.01880 | Murata | GRM21BR71H104MA01L
R32 | 100k | Resistors_SMD:R_0805 | https://www.seielect.com/Catalog/SEI-RMCF_RMCP.pdf | Digikey | RMCF0805JT100KCT-ND | 0.00320 | Stackpole | RMCF0805JT100K
FB6 | Ferrite bead | Resistors_SMD:R_0805 | http://www.samsungsem.com/kr/front/downloadcms.do?fileName=S_CIS21J121NE.pdf | Digikey | 1276-6370-1-ND | 0.02383 | Samsung | CIS21P300NE
C62 | 1uF | Capacitors_SMD:C_0805 | http://www.murata.com/~/media/webrenewal/support/library/catalog/products/capacitor/mlcc/c02e.ashx | Digikey | 490-10743-2-ND | 0.03980 | Murata | GRM219R61H105KA73D
F2 | 2A PTC | Resistors_SMD:R_1812 | http://www.belfuse.com/pdfs/0ZCG.pdf | Digikey | 507-1777-1-ND | 0.09403 | Bel Fuse | 0ZCG0200FF2C
C64 | 0.1uF | Capacitors_SMD:C_0805 | http://psearch.murata.com/capacitor/product/GRM21BR71H104MA01%23.pdf | Digikey | 490-9672-2-ND | 0.01880 | Murata | GRM21BR71H104MA01L
Q2 | 2N7002P | TO_SOT_Packages_SMD:SOT-23 | http://www.nxp.com/documents/data_sheet/2N7002P.pdf | Digikey | 568-5818-1-ND | 0.02936 | NXP | 2N7002P.215
C66 | 1uF | Capacitors_SMD:C_0805 | http://www.murata.com/~/media/webrenewal/support/library/catalog/products/capacitor/mlcc/c02e.ashx | Digikey | 490-10743-2-ND | 0.03980 | Murata | GRM219R61H105KA73D
R33 | 100k | Resistors_SMD:R_0805 | https://www.seielect.com/Catalog/SEI-RMCF_RMCP.pdf | Digikey | RMCF0805JT100KCT-ND | 0.00320 | Stackpole | RMCF0805JT100K
C68 | 0.1uF | Capacitors_SMD:C_0805 | http://psearch.murata.com/capacitor/product/GRM21BR71H104MA01%23.pdf | Digikey | 490-9672-2-ND | 0.01880 | Murata | GRM21BR71H104MA01L
C65 | 0.1uF | Capacitors_SMD:C_0805 | http://psearch.murata.com/capacitor/product/GRM21BR71H104MA01%23.pdf | Digikey | 490-9672-2-ND | 0.01880 | Murata | GRM21BR71H104MA01L
C67 | 1uF | Capacitors_SMD:C_0805 | http://www.murata.com/~/media/webrenewal/support/library/catalog/products/capacitor/mlcc/c02e.ashx | Digikey | 490-10743-2-ND | 0.03980 | Murata | GRM219R61H105KA73D
C69 | 0.1uF | Capacitors_SMD:C_0805 | http://psearch.murata.com/capacitor/product/GRM21BR71H104MA01%23.pdf | Digikey | 490-9672-2-ND | 0.01880 | Murata | GRM21BR71H104MA01L
R34 | 2.2k | Resistors_SMD:R_0805 | http://www.seielect.com/Catalog/SEI-RMCF_RMCP.pdf | Digikey | RMCF0805JT2K20CT-ND | 0.0032 | Stackpole | RMCF0805JT2K20CT
U10 | SiP32408 | TDFN4:TDFN4 | http://www.vishay.com/docs/63717/sip32408.pdf | Digikey | SIP32408DNP-T1-GE4CT-ND | 0.175 | Vishay | SIP32408DNP-T1-GE4
U11 | SiP32408 | TDFN4:TDFN4 | http://www.vishay.com/docs/63717/sip32408.pdf | Digikey | SIP32408DNP-T1-GE4CT-ND | 0.175 | Vishay | SIP32408DNP-T1-GE4
C70 | 10uF | Capacitors_SMD:C_1206 | http://www.murata.com/~/media/webrenewal/support/library/catalog/products/capacitor/mlcc/c02e.ashx | Digikey | 490-10756-2-ND | 0.07429 | Murata | GRM31CR61H106MA12L
C71 | 10uF | Capacitors_SMD:C_1206 | http://www.murata.com/~/media/webrenewal/support/library/catalog/products/capacitor/mlcc/c02e.ashx | Digikey | 490-10756-2-ND | 0.07429 | Murata | GRM31CR61H106MA12L
D8 | 8.5VWM | TO_SOT_Packages_SMD:SOT-23 | http://www.onsemi.com/pub_link/Collateral/MMBZ5V6ALT1-D.PDF | Digikey | MMBZ12VALT1GOSCT-ND | .04471 | ON Semi | MMBZ12VALT1G
C73 | 1uF | Capacitors_SMD:C_0805 | http://www.murata.com/~/media/webrenewal/support/library/catalog/products/capacitor/mlcc/c02e.ashx | Digikey | 490-10743-2-ND | 0.03980 | Murata | GRM219R61H105KA73D
CON4 | 2.5mm 5-24V 5A | Connect:BARREL_JACK | http://katalog.we-online.de/em/datasheet/6941xx105102.pdf | Digikey | 732-5932-1-ND | 1.13 | Wurth | 694108105102
Q3 | AOD4189 | TO_SOT_Packages_SMD:TO-252-2Lead | http://aosmd.com/res/data_sheets/AOD4189.pdf | Digikey | 785-1351-1-ND | 0.196 | Alpha & Omega | AOD4189
C72 | 0.1uF | Capacitors_SMD:C_0805 | http://psearch.murata.com/capacitor/product/GRM21BR71H104MA01%23.pdf | Digikey | 490-9672-2-ND | 0.01880 | Murata | GRM21BR71H104MA01L
CON5 | 5-24V 16A | Terminal_Blocks:TerminalBlock_Pheonix_PT-3.5mm_4pol | http://www.diytrade.com/china/pd/11802786/terminal_block_2EDG_5_08_2P_3P_4P_5P_6P_7P_8P_9P_10P_11P_12P_13P_14P.html | eBay | http://www.ebay.com/itm/331290774584 | 0.23 | E-xun | 2EDG-3.81 |  | 4way 4pin Screw PCB Terminal Block Connector 3.81mm Pitch Pluggable Type
D9 | 8.5VWM | TO_SOT_Packages_SMD:SOT-23 | http://www.onsemi.com/pub_link/Collateral/MMBZ5V6ALT1-D.PDF | Digikey | MMBZ12VALT1GOSCT-ND | .04471 | ON Semi | MMBZ12VALT1G
R35 | 100k | Resistors_SMD:R_0805 | https://www.seielect.com/Catalog/SEI-RMCF_RMCP.pdf | Digikey | RMCF0805JT100KCT-ND | 0.00320 | Stackpole | RMCF0805JT100K
FB7 | Ferrite bead | Resistors_SMD:R_0805 | http://www.samsungsem.com/kr/front/downloadcms.do?fileName=S_CIS21J121NE.pdf | Digikey | 1276-6370-1-ND | 0.02383 | Samsung | CIS21P300NE
FB8 | Ferrite bead | Resistors_SMD:R_0805 | http://www.samsungsem.com/kr/front/downloadcms.do?fileName=S_CIS21J121NE.pdf | Digikey | 1276-6370-1-ND | 0.02383 | Samsung | CIS21P300NE
C77 | 1uF | Capacitors_SMD:C_0805 | http://www.murata.com/~/media/webrenewal/support/library/catalog/products/capacitor/mlcc/c02e.ashx | Digikey | 490-10743-2-ND | 0.03980 | Murata | GRM219R61H105KA73D
C76 | 0.1uF | Capacitors_SMD:C_0805 | http://psearch.murata.com/capacitor/product/GRM21BR71H104MA01%23.pdf | Digikey | 490-9672-2-ND | 0.01880 | Murata | GRM21BR71H104MA01L
U13 | TCR2EF12 | TO_SOT_Packages_SMD:SOT-23-5 | http://www.semicon.toshiba.co.jp/info/docget.jsp?pid=TCR2EE10&lang=en&type=datasheet | Digikey | TCR2EF12LM(CTCT-ND | 0.07110 | Toshiba | TCR2EF12.LM(CT |  | LDO 1.2V 200mA
C75 | 1uF | Capacitors_SMD:C_0805 | http://www.murata.com/~/media/webrenewal/support/library/catalog/products/capacitor/mlcc/c02e.ashx | Digikey | 490-10743-2-ND | 0.03980 | Murata | GRM219R61H105KA73D
C74 | 0.1uF | Capacitors_SMD:C_0805 | http://psearch.murata.com/capacitor/product/GRM21BR71H104MA01%23.pdf | Digikey | 490-9672-2-ND | 0.01880 | Murata | GRM21BR71H104MA01L
U12 | TCR2EF25 | TO_SOT_Packages_SMD:SOT-23-5 | http://www.semicon.toshiba.co.jp/info/docget.jsp?pid=TCR2EE10&lang=en&type=datasheet | Digikey | TCR2EF25LM(CTCT-ND | 0.07110 | Toshiba | TCR2EF25.LM(CT |  | LDO 2.5V 200mA
U14 | Si5351B | Housings_DFN_QFN:QFN-20-1EP_4x4mm_Pitch0.5mm | http://www.silabs.com/Support%20Documents/TechnicalDocs/Si5351-B.pdf | Digikey | 336-2401-5-ND | 2.01798 | Silicon Labs | SI5351B-B-GM
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

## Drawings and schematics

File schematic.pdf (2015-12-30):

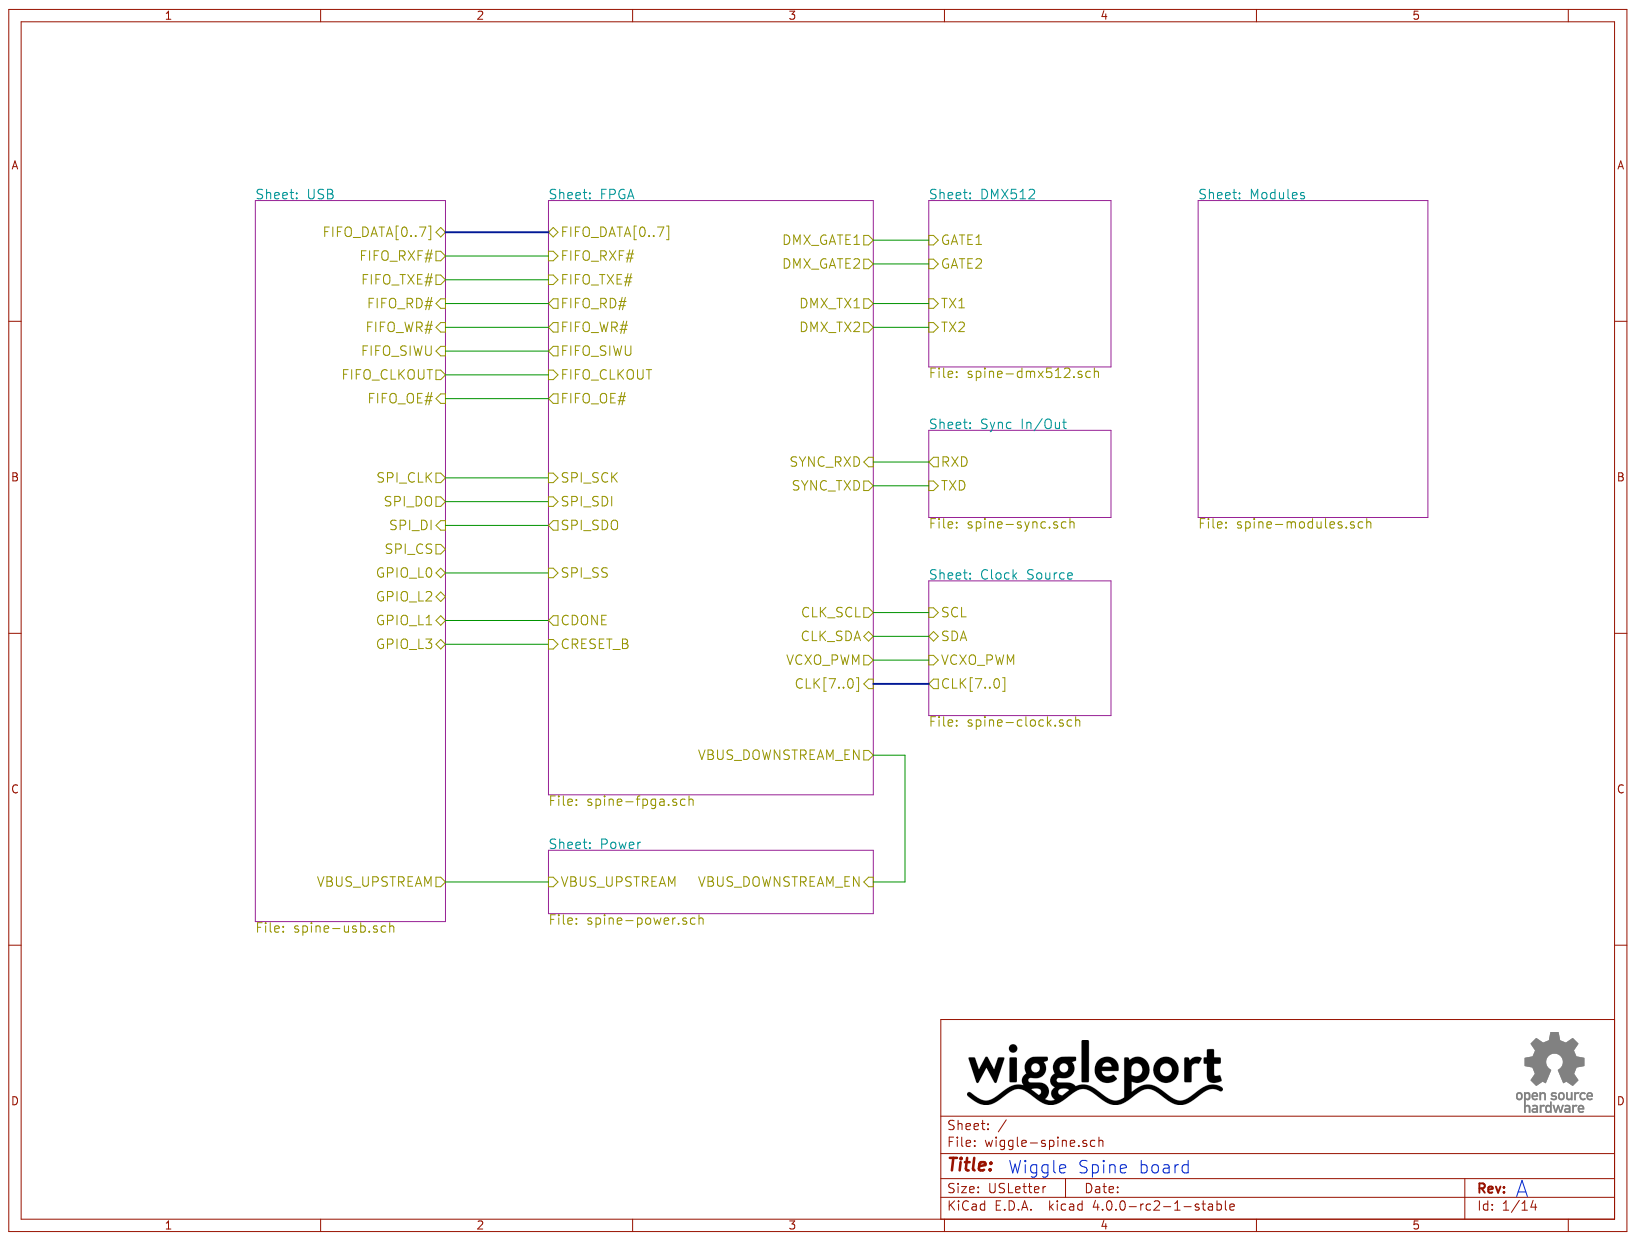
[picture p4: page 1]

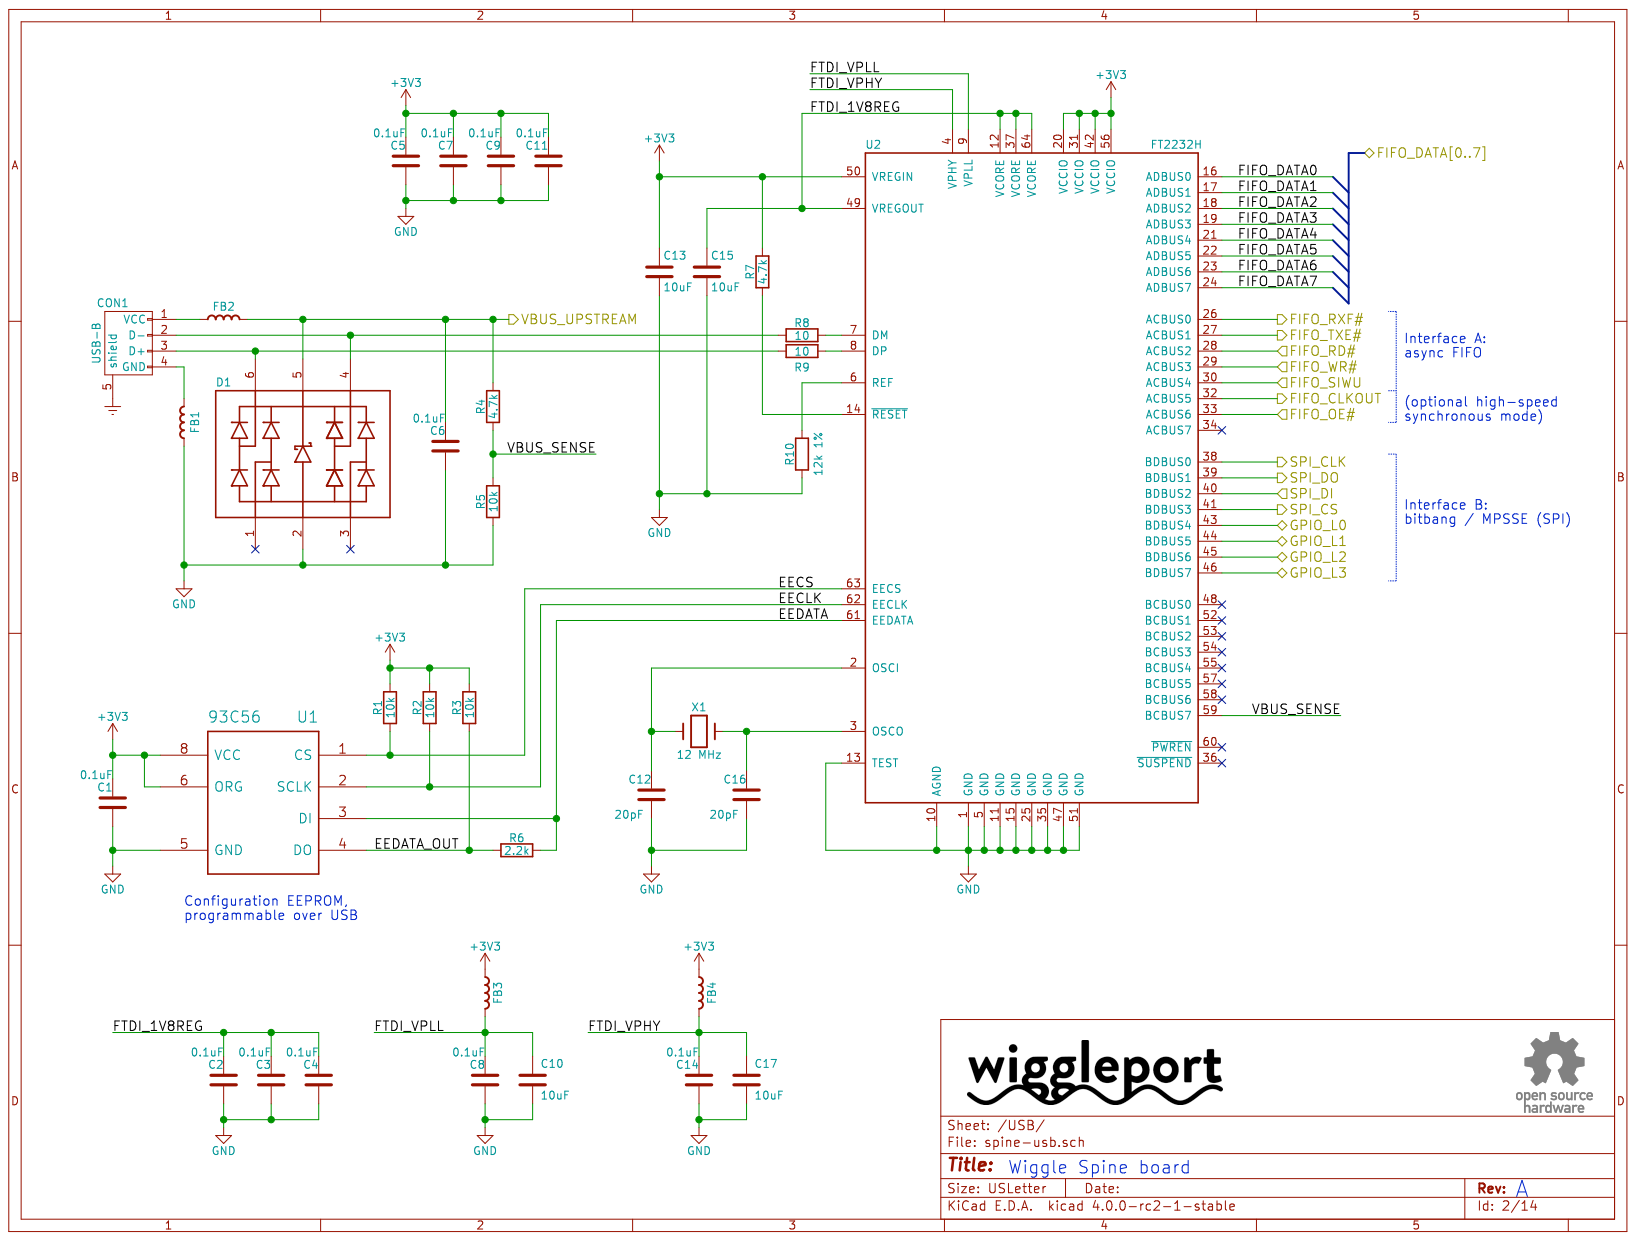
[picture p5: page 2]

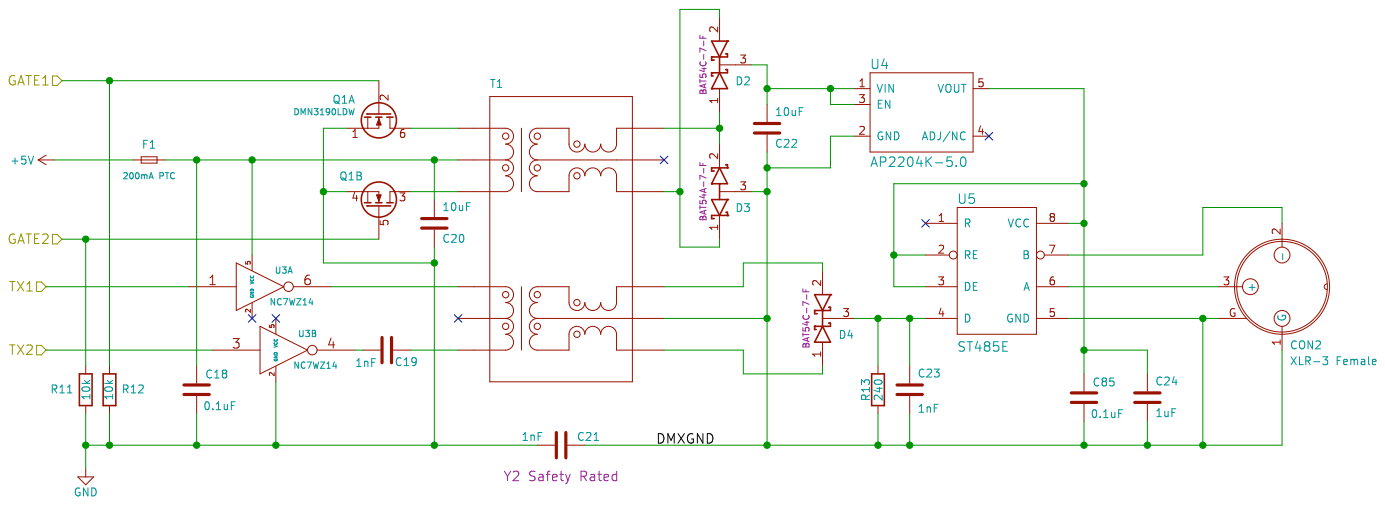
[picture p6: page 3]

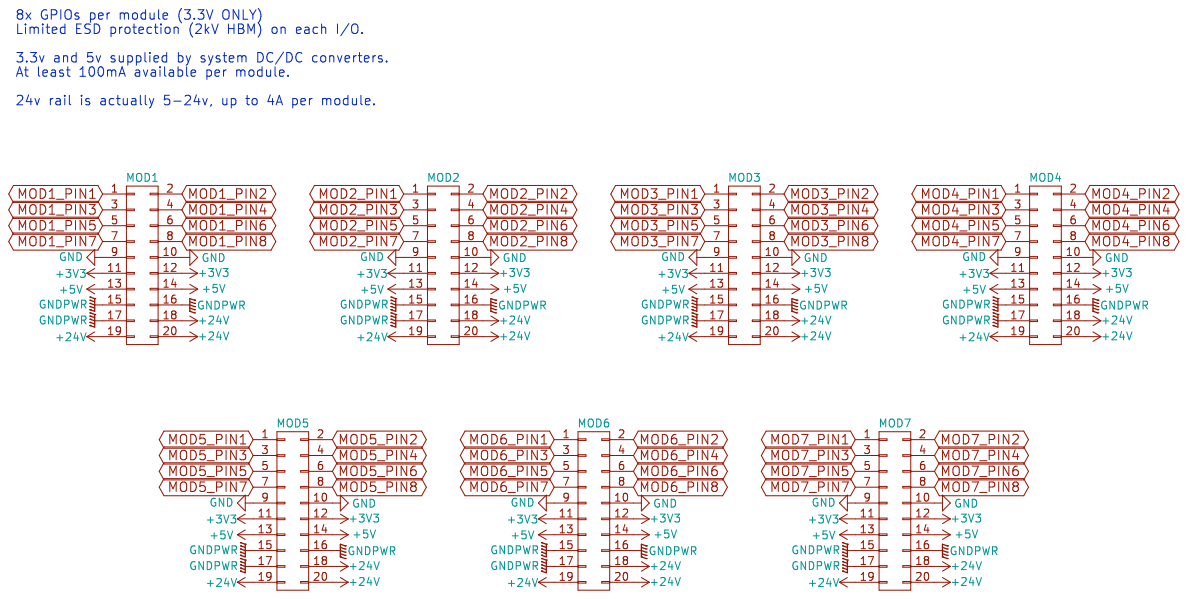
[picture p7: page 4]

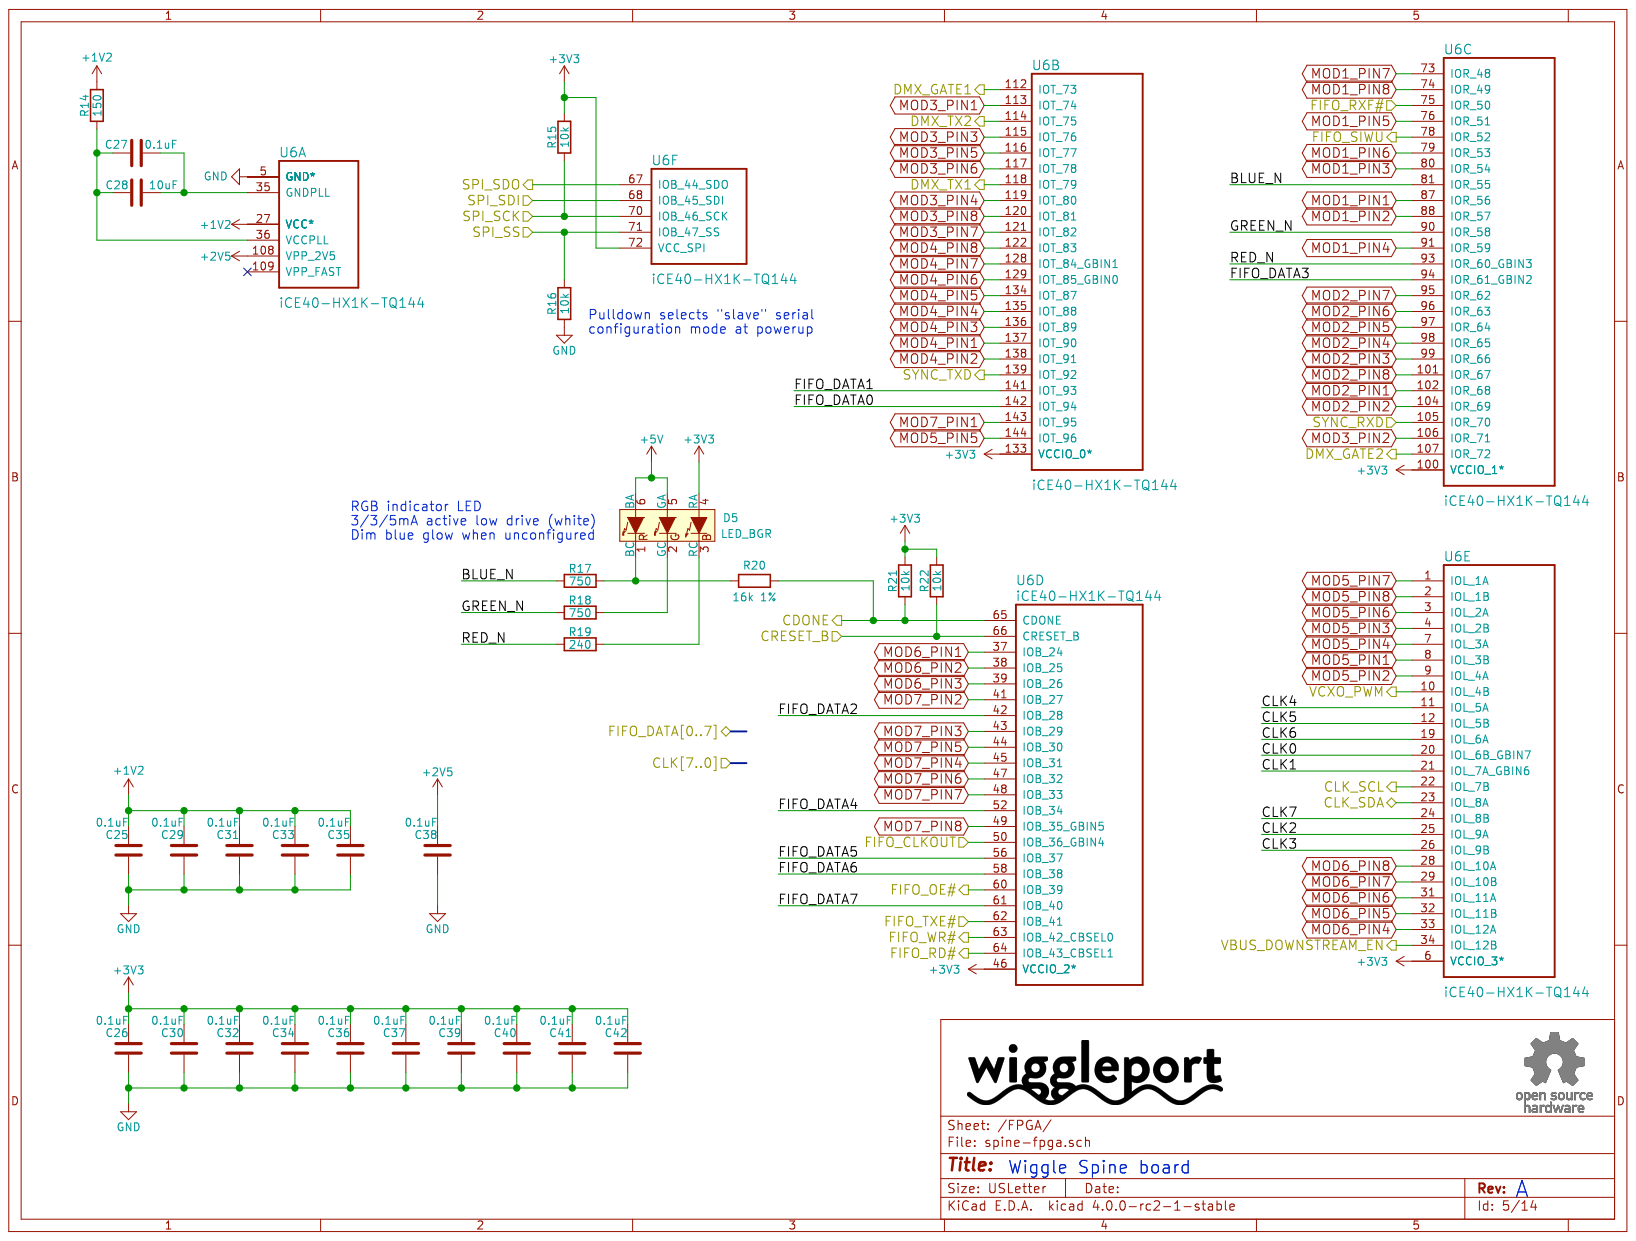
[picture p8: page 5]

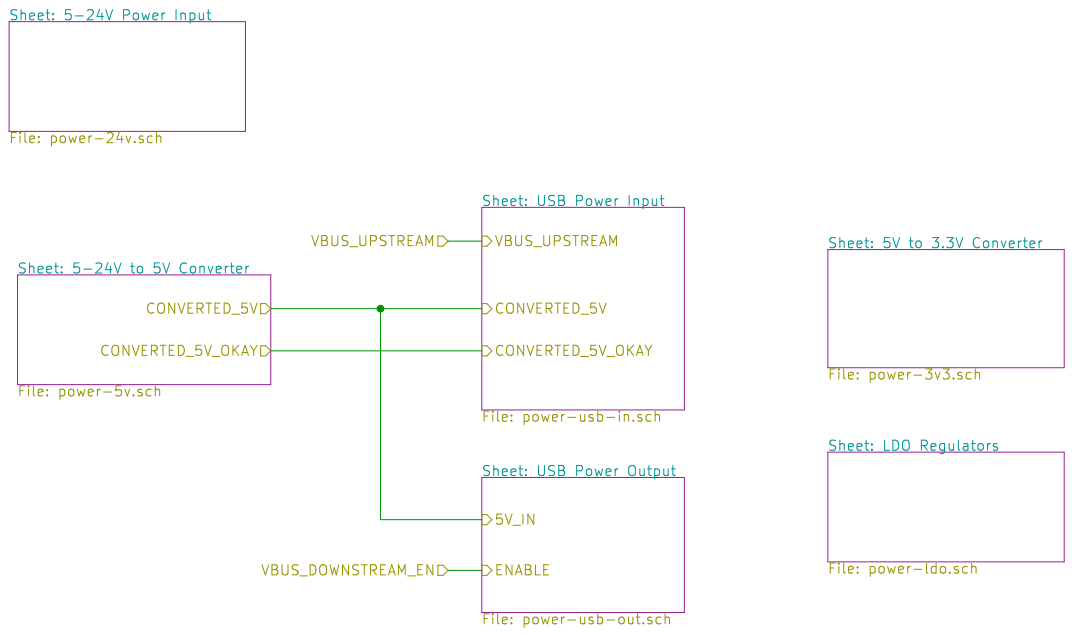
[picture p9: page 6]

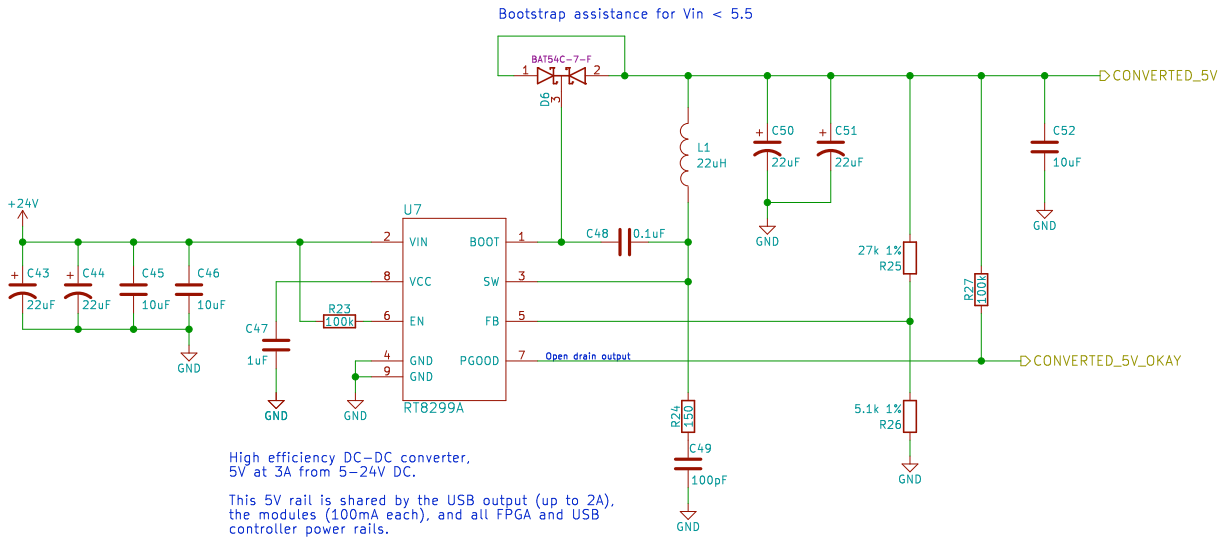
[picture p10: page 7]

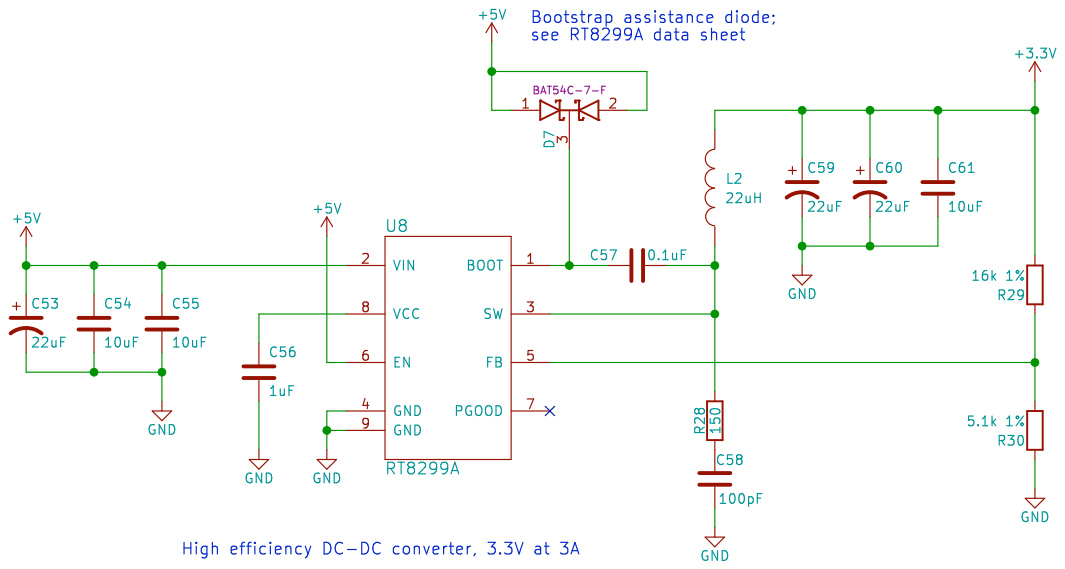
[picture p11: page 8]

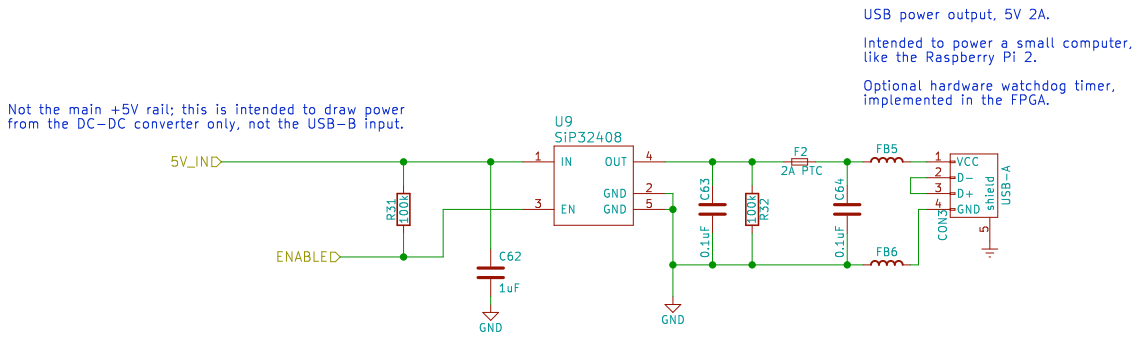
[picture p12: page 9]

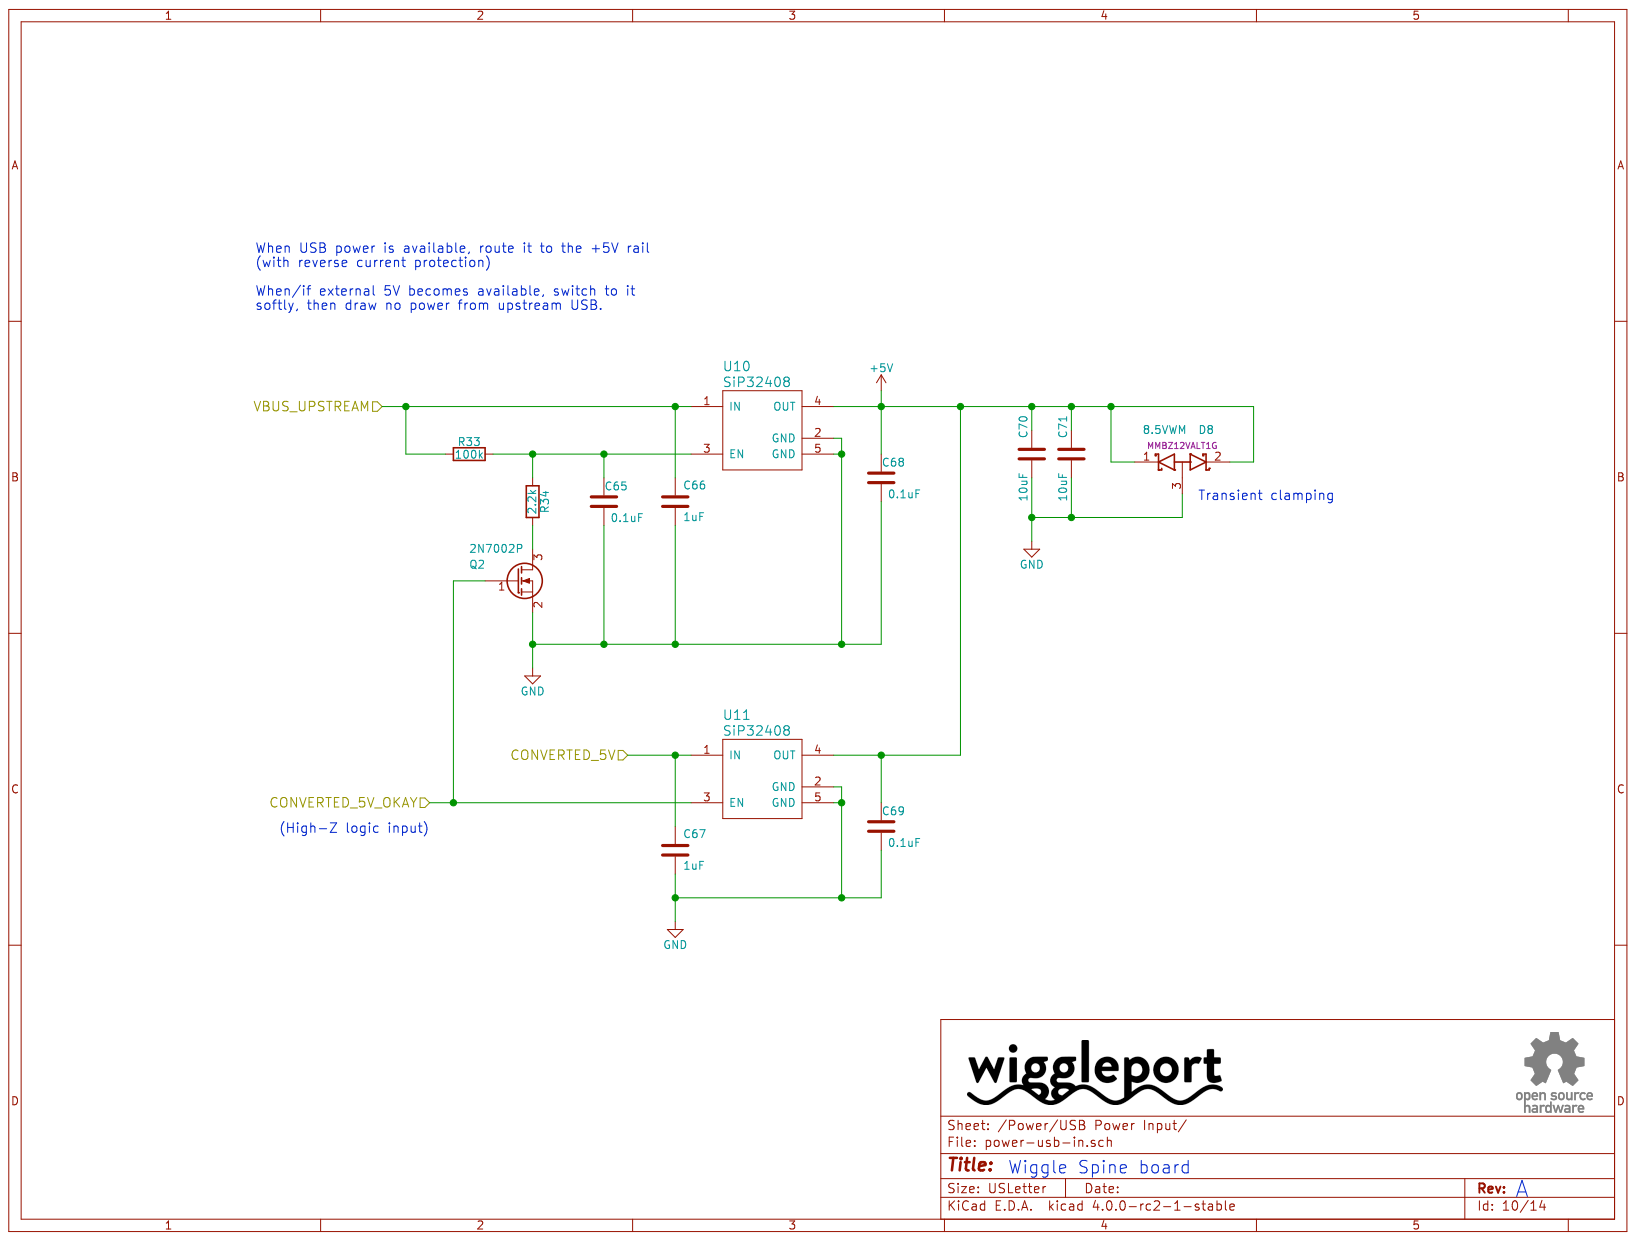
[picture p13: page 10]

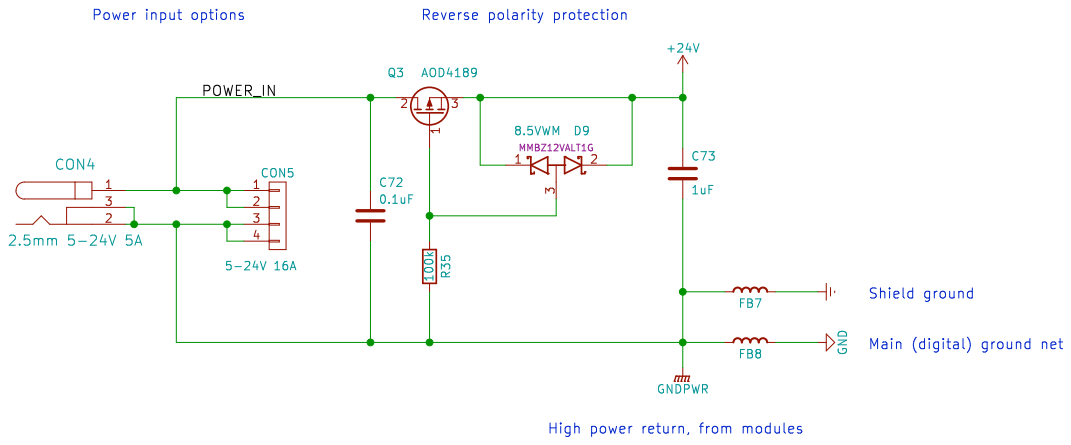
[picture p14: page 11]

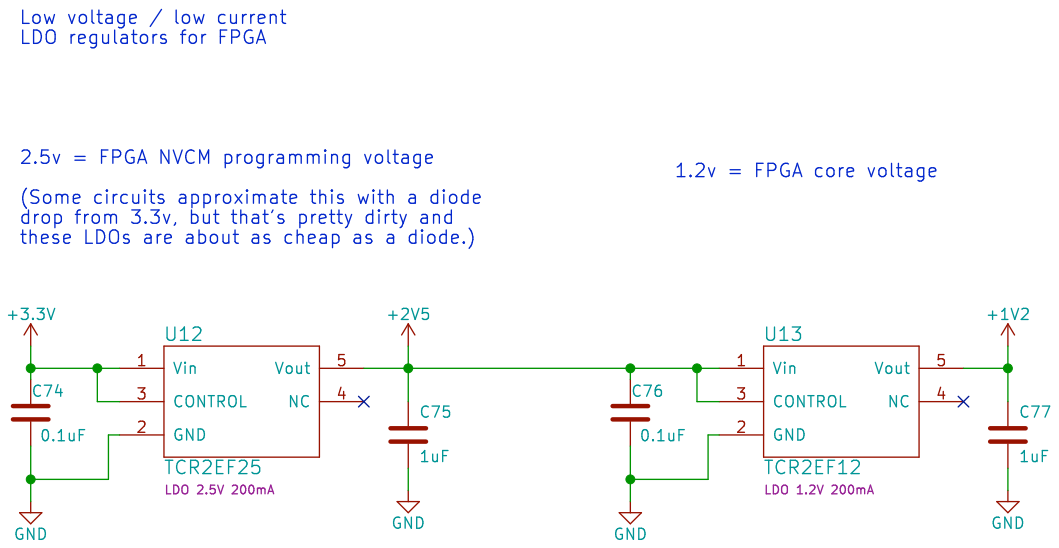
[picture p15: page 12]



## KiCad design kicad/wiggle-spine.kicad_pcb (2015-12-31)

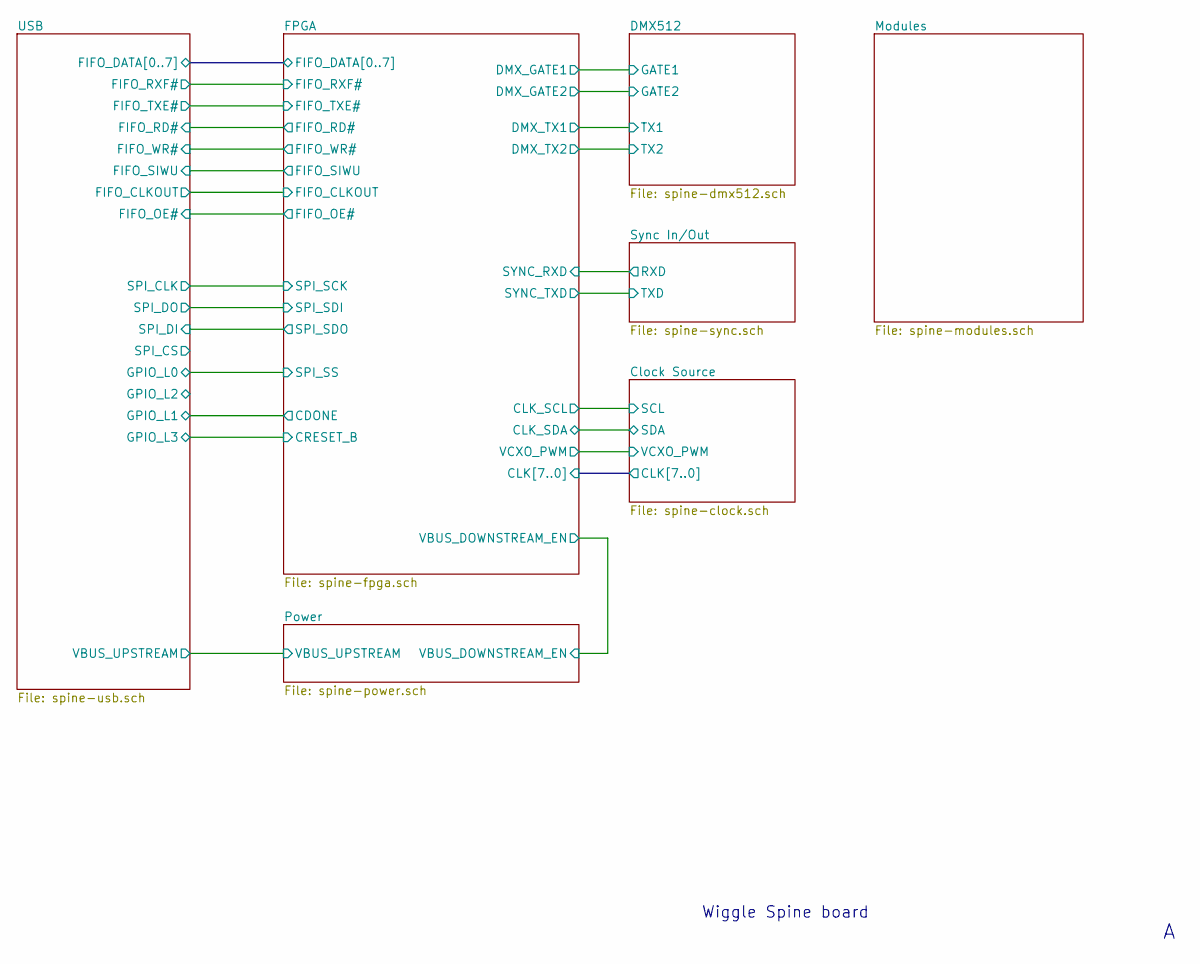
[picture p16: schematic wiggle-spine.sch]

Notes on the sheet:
Wiggle Spine board

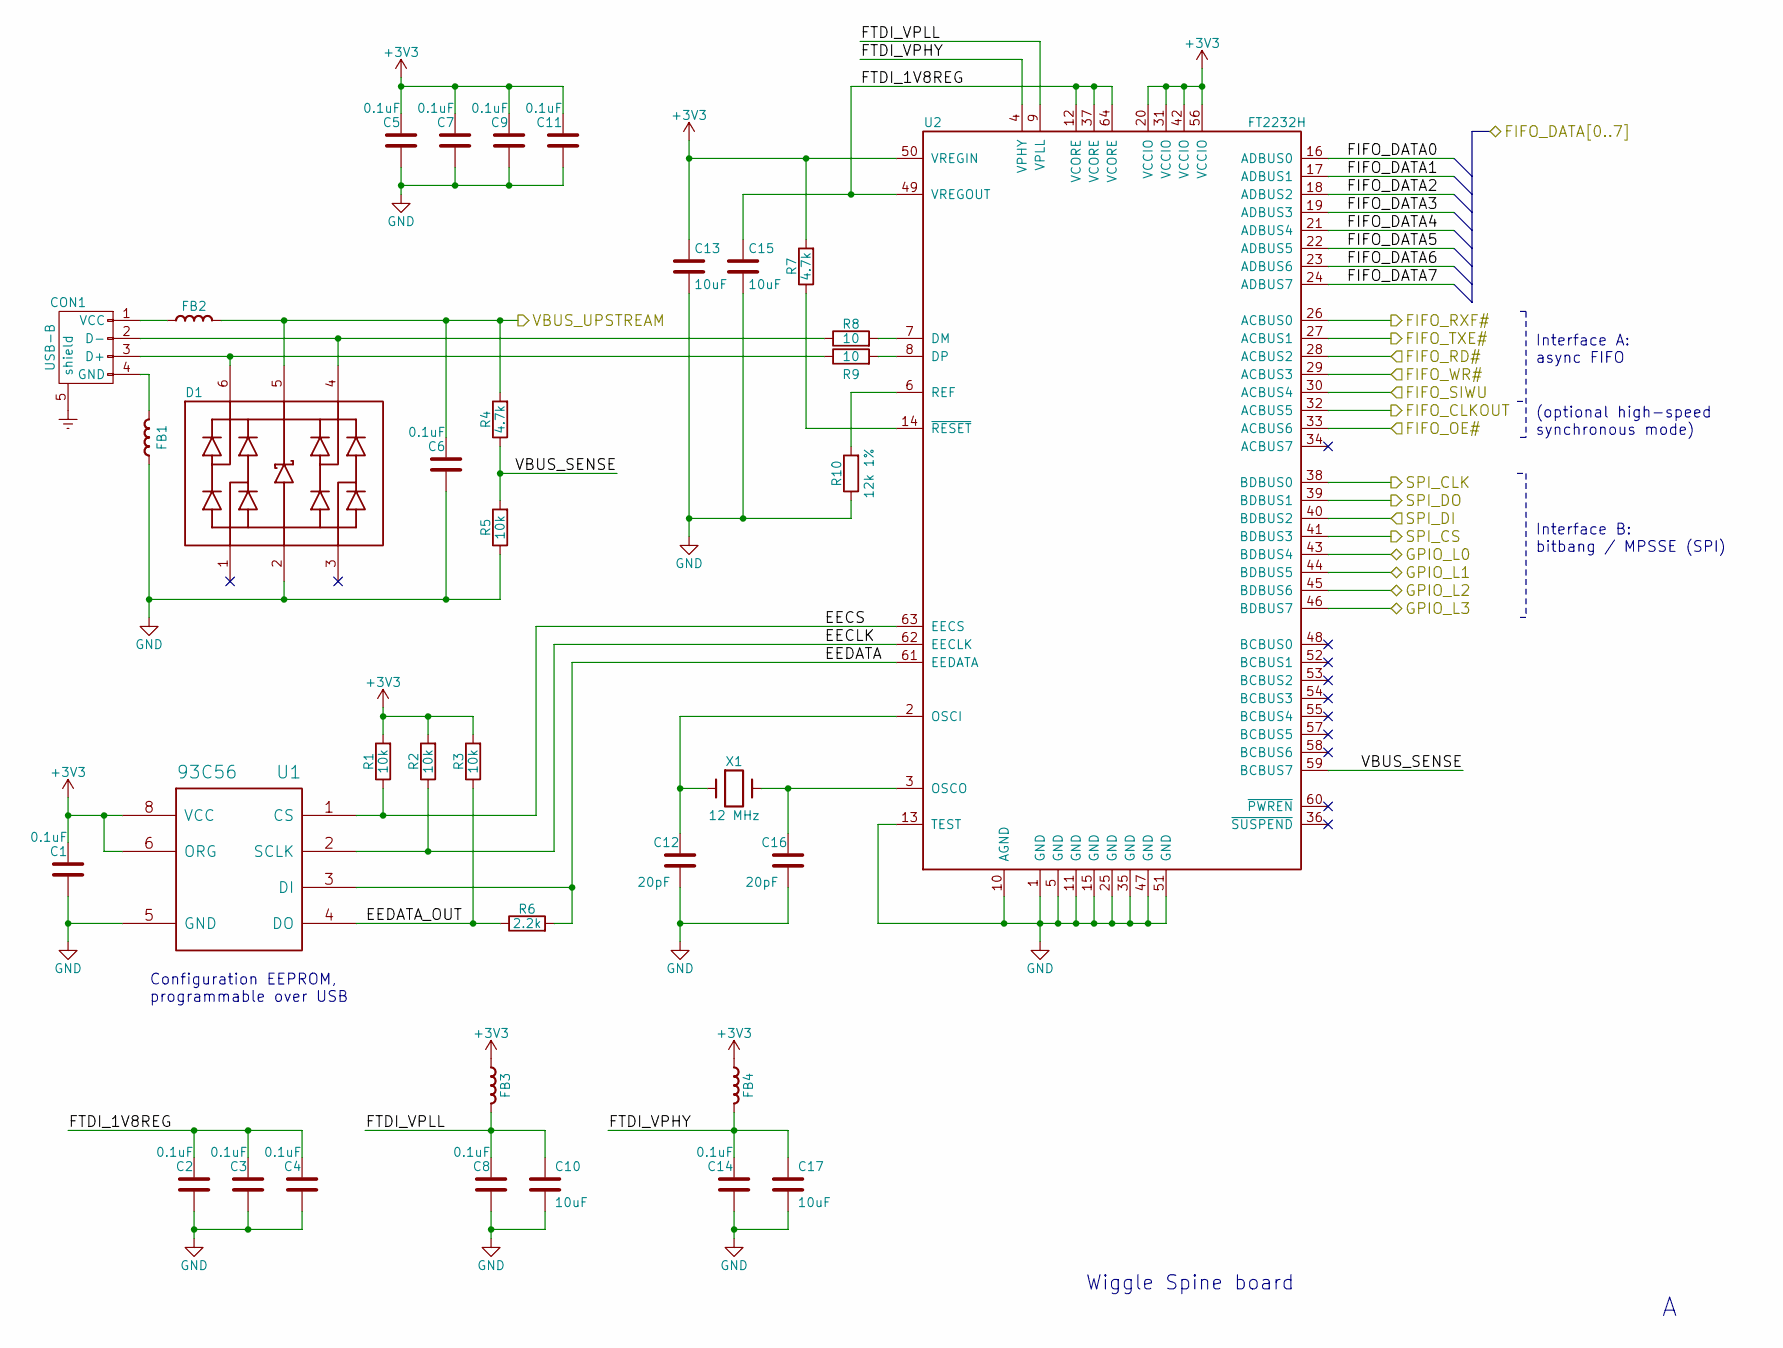
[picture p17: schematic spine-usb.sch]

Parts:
C1, C2, C3, C4, C5, C6, C7, C8, C9, C11, C14: 0.1uF; C_0805
C10, C13, C15, C17: 10uF; C_1206
C12, C16: 20pF; C_0805
CON1: USB-B; USB_B
D1: TVS DIODE 5.5VWM; SC-70-6
FB1, FB2, FB3, FB4: Ferrite bead; R_0805
R1, R2, R3, R5: 10k; R_0805
R4, R7: 4.7k; R_0805
R6: 2.2k; R_0805
R8, R9: 10; R_0805
R10: 12k 1%; R_0805
U1: 93C56; SOIC-8_3.9x4.9mm_Pitch1.27mm
U2: FT2232H; LQFP-64_10x10mm_Pitch0.5mm
X1: 12 MHz; Crystal_HC49-SD_SMD

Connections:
/FPGA/CDONE: U2.44 (BDBUS5); also elsewhere on the board
/FPGA/CRESET_B: U2.46 (BDBUS7); also elsewhere on the board
/FPGA/FIFO_CLKOUT: U2.32 (ACBUS5); also elsewhere on the board
/FPGA/FIFO_DATA0: U2.16 (ADBUS0); also elsewhere on the board
/FPGA/FIFO_DATA1: U2.17 (ADBUS1); also elsewhere on the board
/FPGA/FIFO_DATA2: U2.18 (ADBUS2); also elsewhere on the board
/FPGA/FIFO_DATA3: U2.19 (ADBUS3); also elsewhere on the board
/FPGA/FIFO_DATA4: U2.21 (ADBUS4); also elsewhere on the board
/FPGA/FIFO_DATA5: U2.22 (ADBUS5); also elsewhere on the board
/FPGA/FIFO_DATA6: U2.23 (ADBUS6); also elsewhere on the board
/FPGA/FIFO_DATA7: U2.24 (ADBUS7); also elsewhere on the board
/FPGA/FIFO_OE#: U2.33 (ACBUS6); also elsewhere on the board
/FPGA/FIFO_RD#: U2.28 (ACBUS2); also elsewhere on the board
/FPGA/FIFO_RXF#: U2.26 (ACBUS0); also elsewhere on the board
/FPGA/FIFO_SIWU: U2.30 (ACBUS4); also elsewhere on the board
/FPGA/FIFO_TXE#: U2.27 (ACBUS1); also elsewhere on the board
/FPGA/FIFO_WR#: U2.29 (ACBUS3); also elsewhere on the board
/Power/VBUS_UPSTREAM: C6.2, D1.5, FB2.2, R4.2; also elsewhere on the board
/USB/EECLK: R2.1, U1.2 (SCLK), U2.62 (EECLK)
/USB/EECS: R1.1, U1.1 (CS), U2.63 (EECS)
/USB/EEDATA: R6.2, U1.3 (DI), U2.61 (EEDATA)
/USB/EEDATA_OUT: R3.1, R6.1, U1.4 (DO)
/USB/FTDI_1V8REG: C2.2, C3.2, C4.2, C15.1, U2.12 (VCORE), U2.37 (VCORE), U2.49 (VREGOUT), U2.64 (VCORE)
/USB/FTDI_VPHY: C14.2, C17.1, FB4.2, U2.4 (VPHY)
/USB/FTDI_VPLL: C8.2, C10.1, FB3.2, U2.9 (VPLL)
/USB/GPIO_L0: U2.43 (BDBUS4); also elsewhere on the board
/USB/SPI_CLK: U2.38 (BDBUS0); also elsewhere on the board
/USB/SPI_DI: U2.40 (BDBUS2); also elsewhere on the board
/USB/SPI_DO: U2.39 (BDBUS1); also elsewhere on the board
/USB/VBUS_SENSE: R4.1, R5.2, U2.59 (BCBUS7)
Earth: CON1.5 (shield); also elsewhere on the board
GND: C1.1, C2.1, C3.1, C4.1, C5.1, C6.1, C7.1, C8.1, C9.1, C10.2, C11.1, C12.1, C13.2, C14.1, C15.2, C16.1, C17.2, D1.2, FB1.1, R5.1, R10.1, U1.5 (GND), U2.1 (GND), U2.5 (GND), U2.10 (AGND), U2.11 (GND), U2.13 (TEST), U2.15 (GND), U2.25 (GND), U2.35 (GND), U2.47 (GND), U2.51 (GND); also elsewhere on the board
unnamed: C12.2, U2.2 (OSCI), X1.1
unnamed: C16.2, U2.3 (OSCO), X1.2
unnamed: CON1.1 (VCC), FB2.1
unnamed: CON1.2 (D-), D1.4, R8.1
unnamed: CON1.3 (D+), D1.6, R9.1
unnamed: CON1.4 (GND), FB1.2
unnamed: R7.1, U2.14 (~RESET)
unnamed: R8.2, U2.7 (DM)
unnamed: R9.2, U2.8 (DP)
unnamed: R10.2, U2.6 (REF)

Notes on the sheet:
(optional high-speed synchronous mode)
Interface A: async FIFO
Interface B: bitbang / MPSSE (SPI)
Configuration EEPROM, programmable over USB
Wiggle Spine board

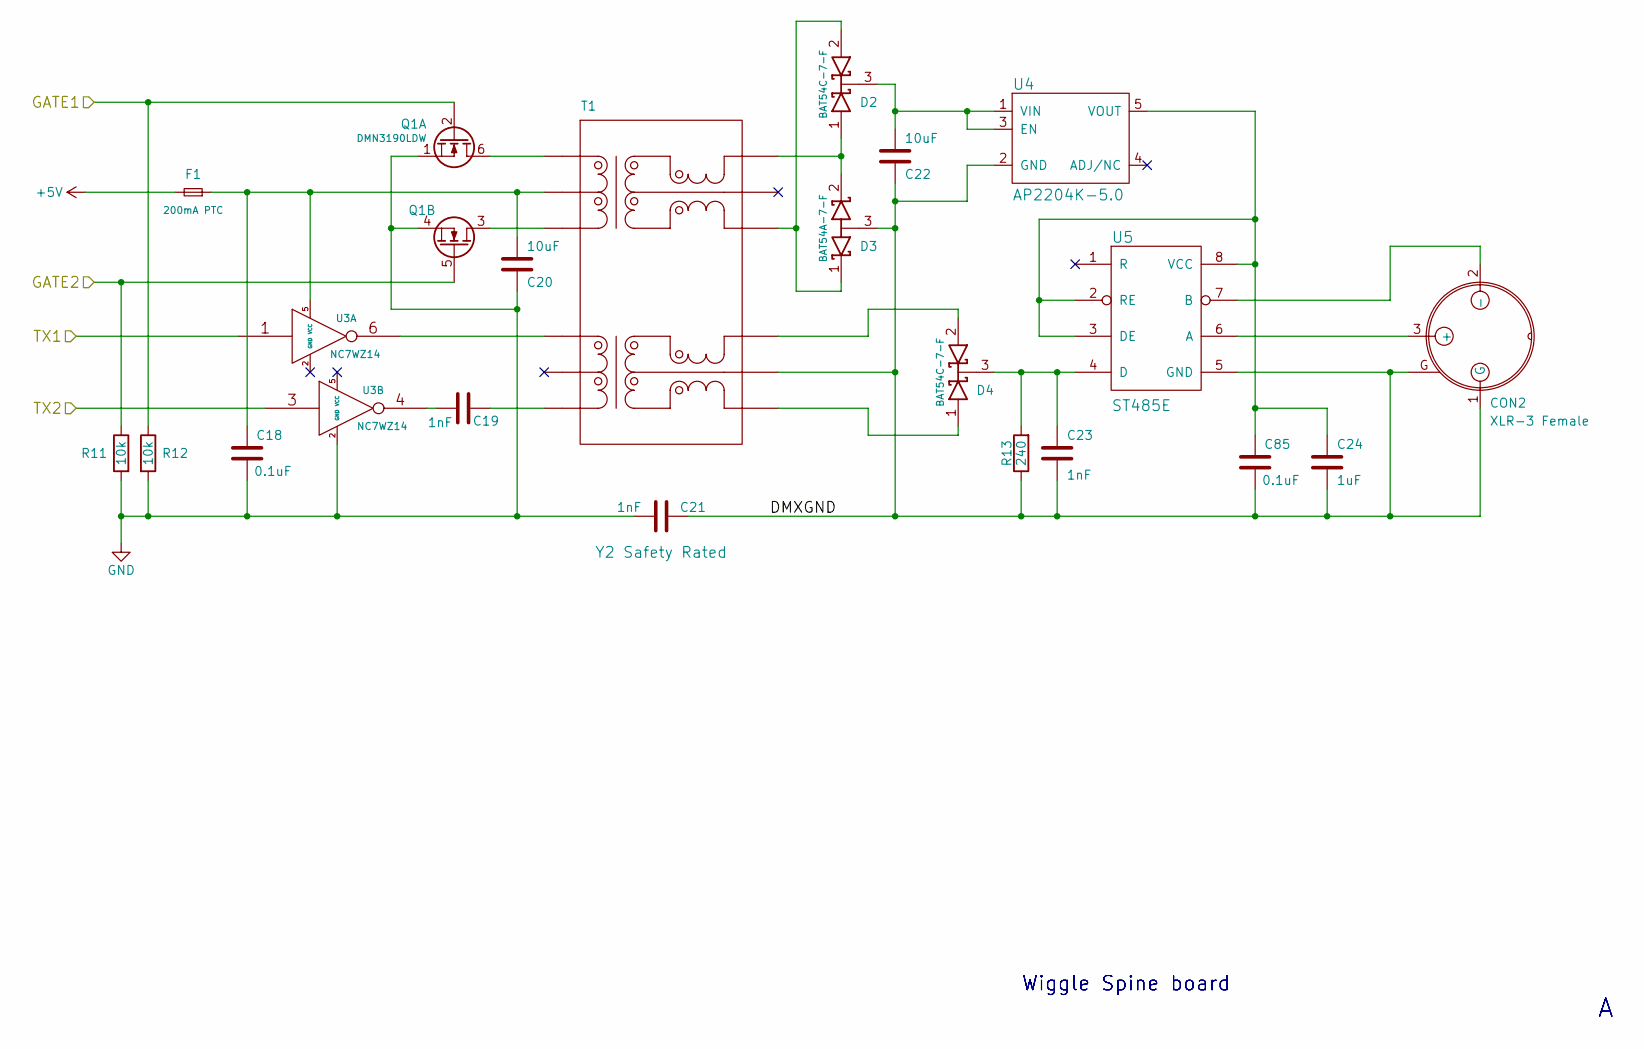
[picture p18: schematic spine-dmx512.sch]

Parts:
C18, C85: 0.1uF; C_0805
C19, C23: 1nF; C_0805
C20, C22: 10uF; C_1206
C21: 1nF; C_1808; Safety Rating Y2 Safety Rated
C24: 1uF; C_0805
CON2: XLR-3 Female; XLR3MC
D2, D4: BAT54 2x common cathode; SOT-23
D3: BAT54 2x common anode; SOT-23
F1: 200mA PTC; R_1206
Q1: DMN3190LDW; SC-70-6
R11, R12: 10k; R_0805
R13: 240; R_0805
T1: 10/100baseT transformer; SOIC-16_7.5x10.3mm_Pitch1.27mm
U3: NC7WZ14; SC-70-6
U4: AP2204K-5.0; SOT-23-5
U5: ST485E; SOIC-8_3.9x4.9mm_Pitch1.27mm

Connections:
+5V: F1.2; also elsewhere on the board
/DMX512/DMXGND: C21.1, C22.2, C23.2, C24.2, C85.1, CON2.1 (G), CON2.G, D3.3 (A), R13.1, T1.7, U4.2 (GND), U5.5 (GND)
/FPGA/DMX_GATE1: Q1.2 (G), R12.1; also elsewhere on the board
/FPGA/DMX_GATE2: Q1.5 (G), R11.1; also elsewhere on the board
/FPGA/DMX_TX1: U3.1; also elsewhere on the board
/FPGA/DMX_TX2: U3.3; also elsewhere on the board
GND: C18.1, C20.2, C21.2, Q1.1 (S), Q1.4 (S), R11.2, R12.2, U3.2 (GND); also elsewhere on the board
unnamed: C18.2, C20.1, F1.1, T1.15, U3.5 (VCC)
unnamed: C19.1, T1.9
unnamed: C19.2, U3.4
unnamed: C22.1, D2.3 (K), U4.1 (VIN), U4.3 (EN)
unnamed: C23.1, D4.3 (K), R13.2, U5.4 (D)
unnamed: C24.1, C85.2, U4.5 (VOUT), U5.2 (RE), U5.3 (DE), U5.8 (VCC)
unnamed: CON2.2 (-), U5.7 (B)
unnamed: CON2.3 (+), U5.6 (A)
unnamed: D2.1 (A), D3.2 (K), T1.1
unnamed: D2.2 (A), D3.1 (K), T1.3
unnamed: D4.1 (A), T1.8
unnamed: D4.2 (A), T1.6
unnamed: Q1.3 (D), T1.14
unnamed: Q1.6 (D), T1.16
unnamed: T1.11, U3.6

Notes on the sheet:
Wiggle Spine board

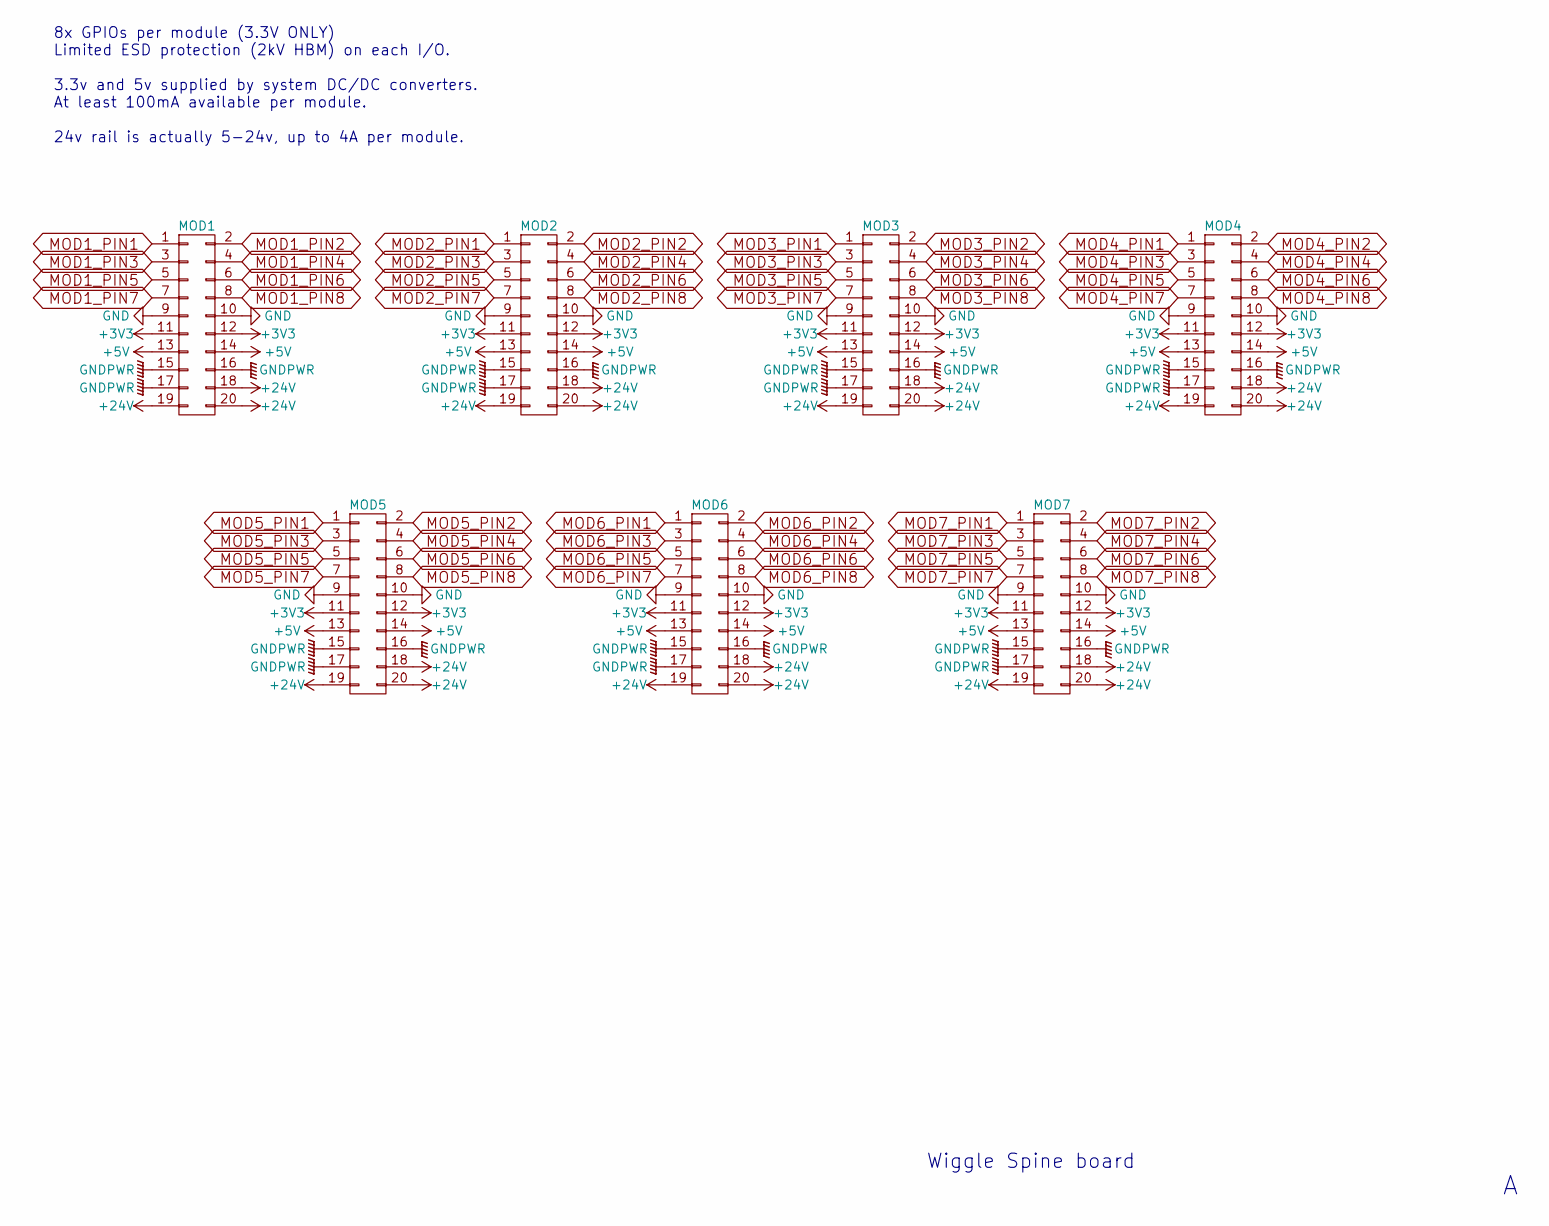
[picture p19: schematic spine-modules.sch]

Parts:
MOD1, MOD2, MOD3, MOD4, MOD5, MOD6, MOD7: 2.54mm 2x10 right angle female header; Socket_Strip_Angled_2x10_Mirror

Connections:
+5V: MOD1.13, MOD1.14, MOD2.13, MOD2.14, MOD3.13, MOD3.14, MOD4.13, MOD4.14, MOD5.13, MOD5.14, MOD6.13, MOD6.14, MOD7.13, MOD7.14; also elsewhere on the board
+24V: MOD1.18, MOD1.19, MOD1.20, MOD2.18, MOD2.19, MOD2.20, MOD3.18, MOD3.19, MOD3.20, MOD4.18, MOD4.19, MOD4.20, MOD5.18, MOD5.19, MOD5.20, MOD6.18, MOD6.19, MOD6.20, MOD7.18, MOD7.19, MOD7.20; also elsewhere on the board
GND: MOD1.9, MOD1.10, MOD2.9, MOD2.10, MOD3.9, MOD3.10, MOD4.9, MOD4.10, MOD5.9, MOD5.10, MOD6.9, MOD6.10, MOD7.9, MOD7.10; also elsewhere on the board
GNDPWR: MOD1.15, MOD1.16, MOD1.17, MOD2.15, MOD2.16, MOD2.17, MOD3.15, MOD3.16, MOD3.17, MOD4.15, MOD4.16, MOD4.17, MOD5.15, MOD5.16, MOD5.17, MOD6.15, MOD6.16, MOD6.17, MOD7.15, MOD7.16, MOD7.17; also elsewhere on the board
MOD1_PIN1: MOD1.1; also elsewhere on the board
MOD1_PIN2: MOD1.2; also elsewhere on the board
MOD1_PIN3: MOD1.3; also elsewhere on the board
MOD1_PIN4: MOD1.4; also elsewhere on the board
MOD1_PIN5: MOD1.5; also elsewhere on the board
MOD1_PIN6: MOD1.6; also elsewhere on the board
MOD1_PIN7: MOD1.7; also elsewhere on the board
MOD1_PIN8: MOD1.8; also elsewhere on the board
MOD2_PIN1: MOD2.1; also elsewhere on the board
MOD2_PIN2: MOD2.2; also elsewhere on the board
MOD2_PIN3: MOD2.3; also elsewhere on the board
MOD2_PIN4: MOD2.4; also elsewhere on the board
MOD2_PIN5: MOD2.5; also elsewhere on the board
MOD2_PIN6: MOD2.6; also elsewhere on the board
MOD2_PIN7: MOD2.7; also elsewhere on the board
MOD2_PIN8: MOD2.8; also elsewhere on the board
MOD3_PIN1: MOD3.1; also elsewhere on the board
MOD3_PIN2: MOD3.2; also elsewhere on the board
MOD3_PIN3: MOD3.3; also elsewhere on the board
MOD3_PIN4: MOD3.4; also elsewhere on the board
MOD3_PIN5: MOD3.5; also elsewhere on the board
MOD3_PIN6: MOD3.6; also elsewhere on the board
MOD3_PIN7: MOD3.7; also elsewhere on the board
MOD3_PIN8: MOD3.8; also elsewhere on the board
MOD4_PIN1: MOD4.1; also elsewhere on the board
MOD4_PIN2: MOD4.2; also elsewhere on the board
MOD4_PIN3: MOD4.3; also elsewhere on the board
MOD4_PIN4: MOD4.4; also elsewhere on the board
MOD4_PIN5: MOD4.5; also elsewhere on the board
MOD4_PIN6: MOD4.6; also elsewhere on the board
MOD4_PIN7: MOD4.7; also elsewhere on the board
MOD4_PIN8: MOD4.8; also elsewhere on the board
MOD5_PIN1: MOD5.1; also elsewhere on the board
MOD5_PIN2: MOD5.2; also elsewhere on the board
MOD5_PIN3: MOD5.3; also elsewhere on the board
MOD5_PIN4: MOD5.4; also elsewhere on the board
MOD5_PIN5: MOD5.5; also elsewhere on the board
MOD5_PIN6: MOD5.6; also elsewhere on the board
MOD5_PIN7: MOD5.7; also elsewhere on the board
MOD5_PIN8: MOD5.8; also elsewhere on the board
MOD6_PIN1: MOD6.1; also elsewhere on the board
MOD6_PIN2: MOD6.2; also elsewhere on the board
MOD6_PIN3: MOD6.3; also elsewhere on the board
MOD6_PIN4: MOD6.4; also elsewhere on the board
MOD6_PIN5: MOD6.5; also elsewhere on the board
MOD6_PIN6: MOD6.6; also elsewhere on the board
MOD6_PIN7: MOD6.7; also elsewhere on the board
MOD6_PIN8: MOD6.8; also elsewhere on the board
MOD7_PIN1: MOD7.1; also elsewhere on the board
MOD7_PIN2: MOD7.2; also elsewhere on the board
MOD7_PIN3: MOD7.3; also elsewhere on the board
MOD7_PIN4: MOD7.4; also elsewhere on the board
MOD7_PIN5: MOD7.5; also elsewhere on the board
MOD7_PIN6: MOD7.6; also elsewhere on the board
MOD7_PIN7: MOD7.7; also elsewhere on the board
MOD7_PIN8: MOD7.8; also elsewhere on the board

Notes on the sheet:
8x GPIOs per module (3.3V ONLY) Limited ESD protection (2kV HBM) on each I/O. 3.3v and 5v supplied by system DC/DC converters. At least 100mA available per module. 24v rail is actually 5-24v, up to 4A per module.
Wiggle Spine board

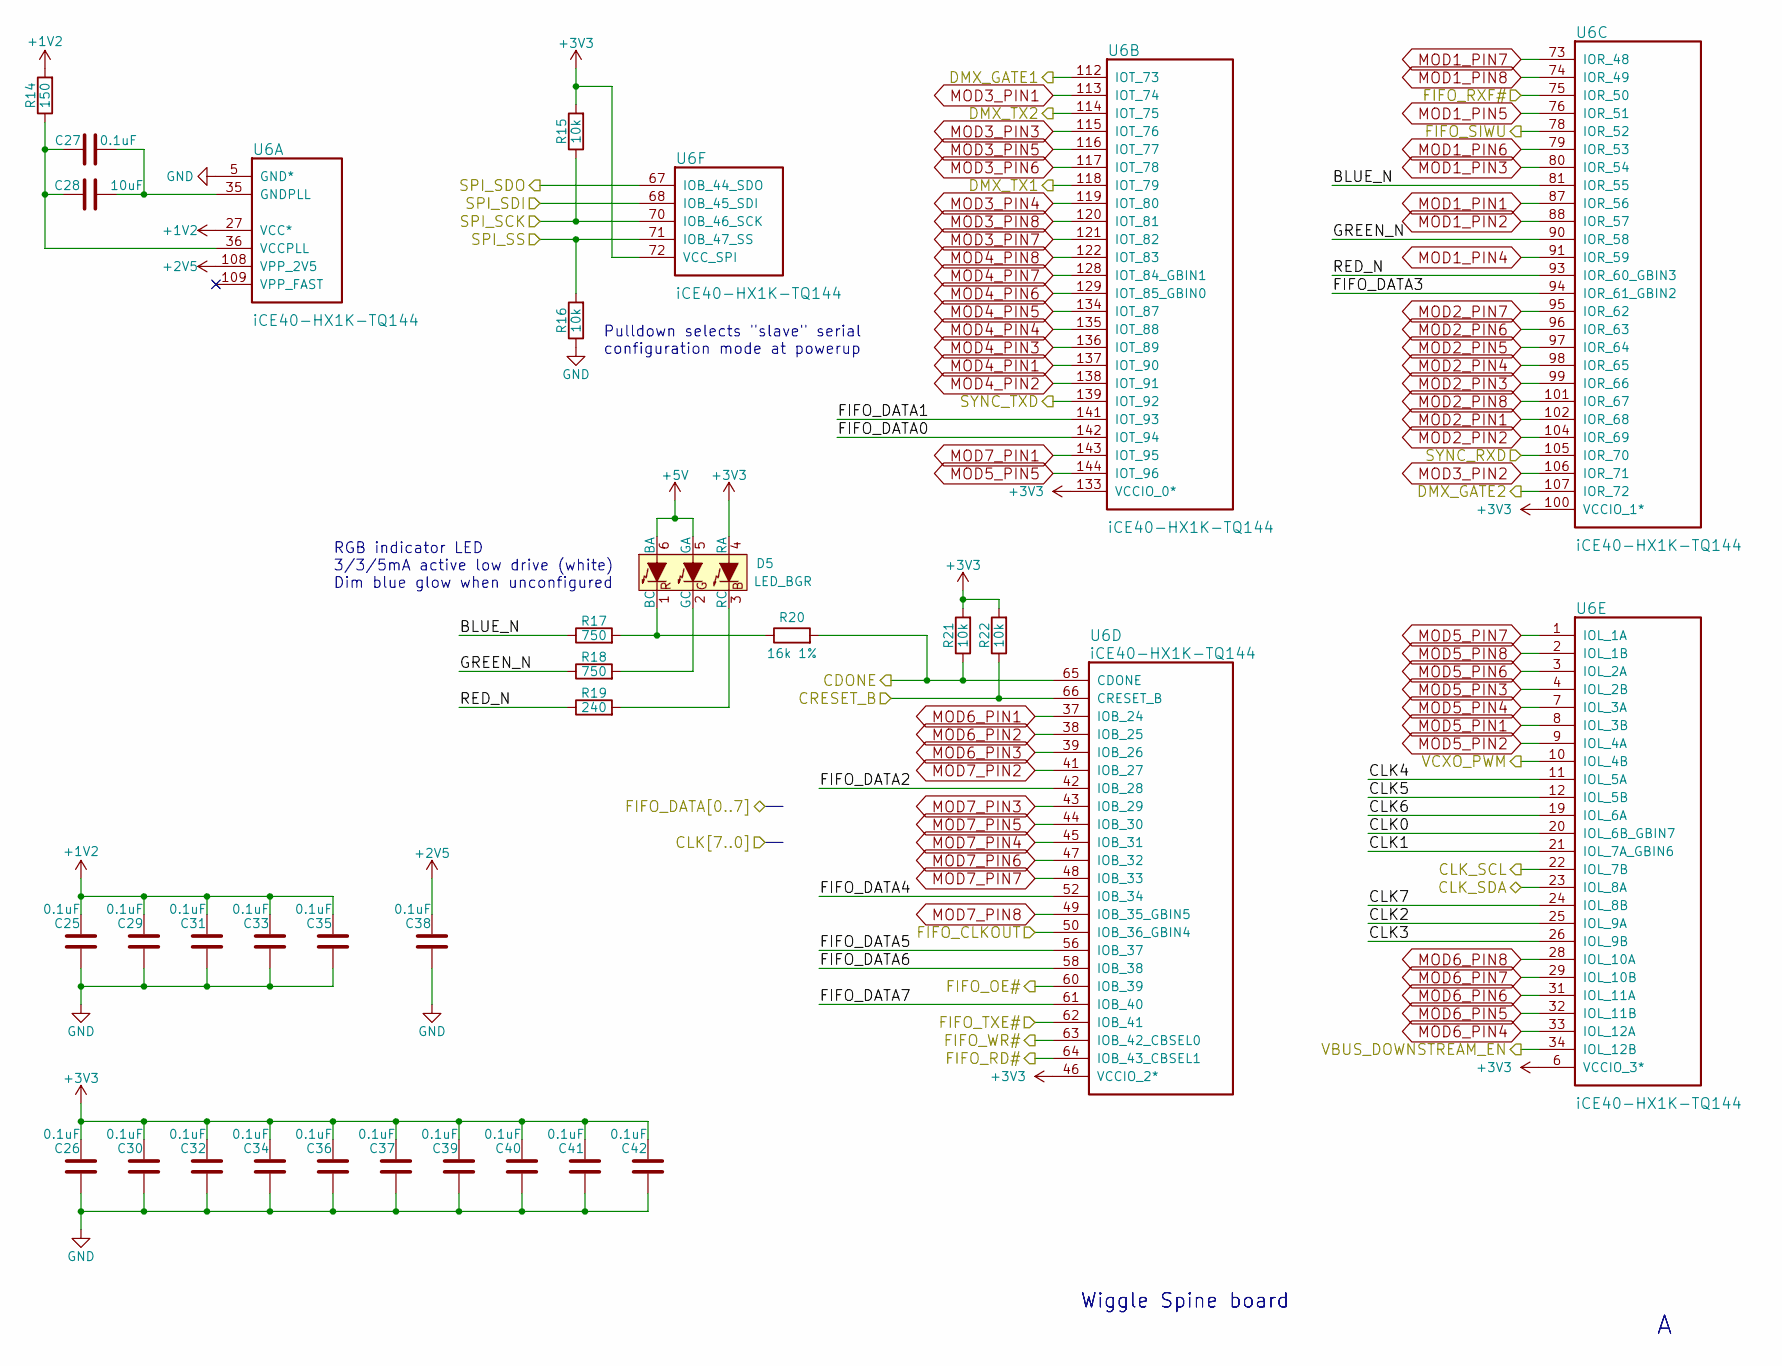
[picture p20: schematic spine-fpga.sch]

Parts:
C25, C26, C27, C29, C30, C31, C32, C33, C34, C35, C36, C37, C38, C39, C40, C41, C42: 0.1uF; C_0805
C28: 10uF; C_1206
D5: LED_BGR; LED_RGB_PLLC-6
R14: 150; R_0805
R15, R16, R21, R22: 10k; R_0805
R17, R18: 750; R_0805
R19: 240; R_0805
R20: 16k 1%; R_0805
U6: iCE40-HX1K-TQ144; TQFP-144_20x20mm_Pitch0.5mm

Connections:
+1V2: C25.2, C29.2, C31.2, C33.2, C35.2, R14.2, U6.27 (VCC*), U6.51 (VCC*), U6.92 (VCC*), U6.111 (VCC*); also elsewhere on the board
+2V5: C38.2, U6.108 (VPP_2V5); also elsewhere on the board
+5V: D5.5 (GA), D5.6 (BA); also elsewhere on the board
/Clock Source/CLK0: U6.20 (IOL_6B_GBIN7); also elsewhere on the board
/Clock Source/CLK1: U6.21 (IOL_7A_GBIN6); also elsewhere on the board
/Clock Source/CLK2: U6.25 (IOL_9A); also elsewhere on the board
/Clock Source/CLK3: U6.26 (IOL_9B); also elsewhere on the board
/Clock Source/CLK4: U6.11 (IOL_5A); also elsewhere on the board
/Clock Source/CLK5: U6.12 (IOL_5B); also elsewhere on the board
/Clock Source/CLK6: U6.19 (IOL_6A); also elsewhere on the board
/Clock Source/CLK7: U6.24 (IOL_8B); also elsewhere on the board
/Clock Source/VCXO_PWM: U6.10 (IOL_4B); also elsewhere on the board
/FPGA/BLUE_N: R17.1, U6.81 (IOR_55)
/FPGA/CDONE: R20.2, R21.1, U6.65 (CDONE); also elsewhere on the board
/FPGA/CLK_SCL: U6.22 (IOL_7B); also elsewhere on the board
/FPGA/CLK_SDA: U6.23 (IOL_8A); also elsewhere on the board
/FPGA/CRESET_B: R22.1, U6.66 (CRESET_B); also elsewhere on the board
/FPGA/DMX_GATE1: U6.112 (IOT_73); also elsewhere on the board
/FPGA/DMX_GATE2: U6.107 (IOR_72); also elsewhere on the board
/FPGA/DMX_TX1: U6.118 (IOT_79); also elsewhere on the board
/FPGA/DMX_TX2: U6.114 (IOT_75); also elsewhere on the board
/FPGA/FIFO_CLKOUT: U6.50 (IOB_36_GBIN4); also elsewhere on the board
/FPGA/FIFO_DATA0: U6.142 (IOT_94); also elsewhere on the board
/FPGA/FIFO_DATA1: U6.141 (IOT_93); also elsewhere on the board
/FPGA/FIFO_DATA2: U6.42 (IOB_28); also elsewhere on the board
/FPGA/FIFO_DATA3: U6.94 (IOR_61_GBIN2); also elsewhere on the board
/FPGA/FIFO_DATA4: U6.52 (IOB_34); also elsewhere on the board
/FPGA/FIFO_DATA5: U6.56 (IOB_37); also elsewhere on the board
/FPGA/FIFO_DATA6: U6.58 (IOB_38); also elsewhere on the board
/FPGA/FIFO_DATA7: U6.61 (IOB_40); also elsewhere on the board
/FPGA/FIFO_OE#: U6.60 (IOB_39); also elsewhere on the board
/FPGA/FIFO_RD#: U6.64 (IOB_43_CBSEL1); also elsewhere on the board
/FPGA/FIFO_RXF#: U6.75 (IOR_50); also elsewhere on the board
/FPGA/FIFO_SIWU: U6.78 (IOR_52); also elsewhere on the board
/FPGA/FIFO_TXE#: U6.62 (IOB_41); also elsewhere on the board
/FPGA/FIFO_WR#: U6.63 (IOB_42_CBSEL0); also elsewhere on the board
/FPGA/GREEN_N: R18.1, U6.90 (IOR_58)
/FPGA/RED_N: R19.1, U6.93 (IOR_60_GBIN3)
/FPGA/SYNC_TXD: U6.139 (IOT_92); also elsewhere on the board
/FPGA/VBUS_DOWNSTREAM_EN: U6.34 (IOL_12B); also elsewhere on the board
/Sync In/Out/RXD: U6.105 (IOR_70); also elsewhere on the board
/USB/GPIO_L0: R16.2, U6.71 (IOB_47_SS); also elsewhere on the board
/USB/SPI_CLK: R15.1, U6.70 (IOB_46_SCK); also elsewhere on the board
/USB/SPI_DI: U6.67 (IOB_44_SDO); also elsewhere on the board
/USB/SPI_DO: U6.68 (IOB_45_SDI); also elsewhere on the board
GND: C25.1, C26.1, C29.1, C30.1, C31.1, C32.1, C33.1, C34.1, C35.1, C36.1, C37.1, C38.1, C39.1, C40.1, C41.1, C42.1, R16.1, U6.5 (GND*), U6.13 (GND*), U6.14 (GND*), U6.59 (GND*), U6.69 (GND*), U6.86 (GND*), U6.103 (GND*), U6.132 (GND*), U6.140 (GND*); also elsewhere on the board
MOD1_PIN1: U6.87 (IOR_56); also elsewhere on the board
MOD1_PIN2: U6.88 (IOR_57); also elsewhere on the board
MOD1_PIN3: U6.80 (IOR_54); also elsewhere on the board
MOD1_PIN4: U6.91 (IOR_59); also elsewhere on the board
MOD1_PIN5: U6.76 (IOR_51); also elsewhere on the board
MOD1_PIN6: U6.79 (IOR_53); also elsewhere on the board
MOD1_PIN7: U6.73 (IOR_48); also elsewhere on the board
MOD1_PIN8: U6.74 (IOR_49); also elsewhere on the board
MOD2_PIN1: U6.102 (IOR_68); also elsewhere on the board
MOD2_PIN2: U6.104 (IOR_69); also elsewhere on the board
MOD2_PIN3: U6.99 (IOR_66); also elsewhere on the board
MOD2_PIN4: U6.98 (IOR_65); also elsewhere on the board
MOD2_PIN5: U6.97 (IOR_64); also elsewhere on the board
MOD2_PIN6: U6.96 (IOR_63); also elsewhere on the board
MOD2_PIN7: U6.95 (IOR_62); also elsewhere on the board
MOD2_PIN8: U6.101 (IOR_67); also elsewhere on the board
MOD3_PIN1: U6.113 (IOT_74); also elsewhere on the board
MOD3_PIN2: U6.106 (IOR_71); also elsewhere on the board
MOD3_PIN3: U6.115 (IOT_76); also elsewhere on the board
MOD3_PIN4: U6.119 (IOT_80); also elsewhere on the board
MOD3_PIN5: U6.116 (IOT_77); also elsewhere on the board
MOD3_PIN6: U6.117 (IOT_78); also elsewhere on the board
MOD3_PIN7: U6.121 (IOT_82); also elsewhere on the board
MOD3_PIN8: U6.120 (IOT_81); also elsewhere on the board
MOD4_PIN1: U6.137 (IOT_90); also elsewhere on the board
MOD4_PIN2: U6.138 (IOT_91); also elsewhere on the board
MOD4_PIN3: U6.136 (IOT_89); also elsewhere on the board
MOD4_PIN4: U6.135 (IOT_88); also elsewhere on the board
MOD4_PIN5: U6.134 (IOT_87); also elsewhere on the board
MOD4_PIN6: U6.129 (IOT_85_GBIN0); also elsewhere on the board
MOD4_PIN7: U6.128 (IOT_84_GBIN1); also elsewhere on the board
MOD4_PIN8: U6.122 (IOT_83); also elsewhere on the board
MOD5_PIN1: U6.8 (IOL_3B); also elsewhere on the board
MOD5_PIN2: U6.9 (IOL_4A); also elsewhere on the board
MOD5_PIN3: U6.4 (IOL_2B); also elsewhere on the board
MOD5_PIN4: U6.7 (IOL_3A); also elsewhere on the board
MOD5_PIN5: U6.144 (IOT_96); also elsewhere on the board
MOD5_PIN6: U6.3 (IOL_2A); also elsewhere on the board
MOD5_PIN7: U6.1 (IOL_1A); also elsewhere on the board
MOD5_PIN8: U6.2 (IOL_1B); also elsewhere on the board
MOD6_PIN1: U6.37 (IOB_24); also elsewhere on the board
MOD6_PIN2: U6.38 (IOB_25); also elsewhere on the board
MOD6_PIN3: U6.39 (IOB_26); also elsewhere on the board
MOD6_PIN4: U6.33 (IOL_12A); also elsewhere on the board
MOD6_PIN5: U6.32 (IOL_11B); also elsewhere on the board
MOD6_PIN6: U6.31 (IOL_11A); also elsewhere on the board
MOD6_PIN7: U6.29 (IOL_10B); also elsewhere on the board
MOD6_PIN8: U6.28 (IOL_10A); also elsewhere on the board
MOD7_PIN1: U6.143 (IOT_95); also elsewhere on the board
MOD7_PIN2: U6.41 (IOB_27); also elsewhere on the board
MOD7_PIN3: U6.43 (IOB_29); also elsewhere on the board
MOD7_PIN4: U6.45 (IOB_31); also elsewhere on the board
MOD7_PIN5: U6.44 (IOB_30); also elsewhere on the board
MOD7_PIN6: U6.47 (IOB_32); also elsewhere on the board
MOD7_PIN7: U6.48 (IOB_33); also elsewhere on the board
MOD7_PIN8: U6.49 (IOB_35_GBIN5); also elsewhere on the board
unnamed: C27.1, C28.2, U6.35 (GNDPLL)
unnamed: C27.2, C28.1, R14.1, U6.36 (VCCPLL)
unnamed: D5.1 (BC), R17.2, R20.1
unnamed: D5.2 (GC), R18.2
unnamed: D5.3 (RC), R19.2

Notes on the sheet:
Pulldown selects "slave" serial configuration mode at powerup
RGB indicator LED 3/3/5mA active low drive (white) Dim blue glow when unconfigured
Wiggle Spine board

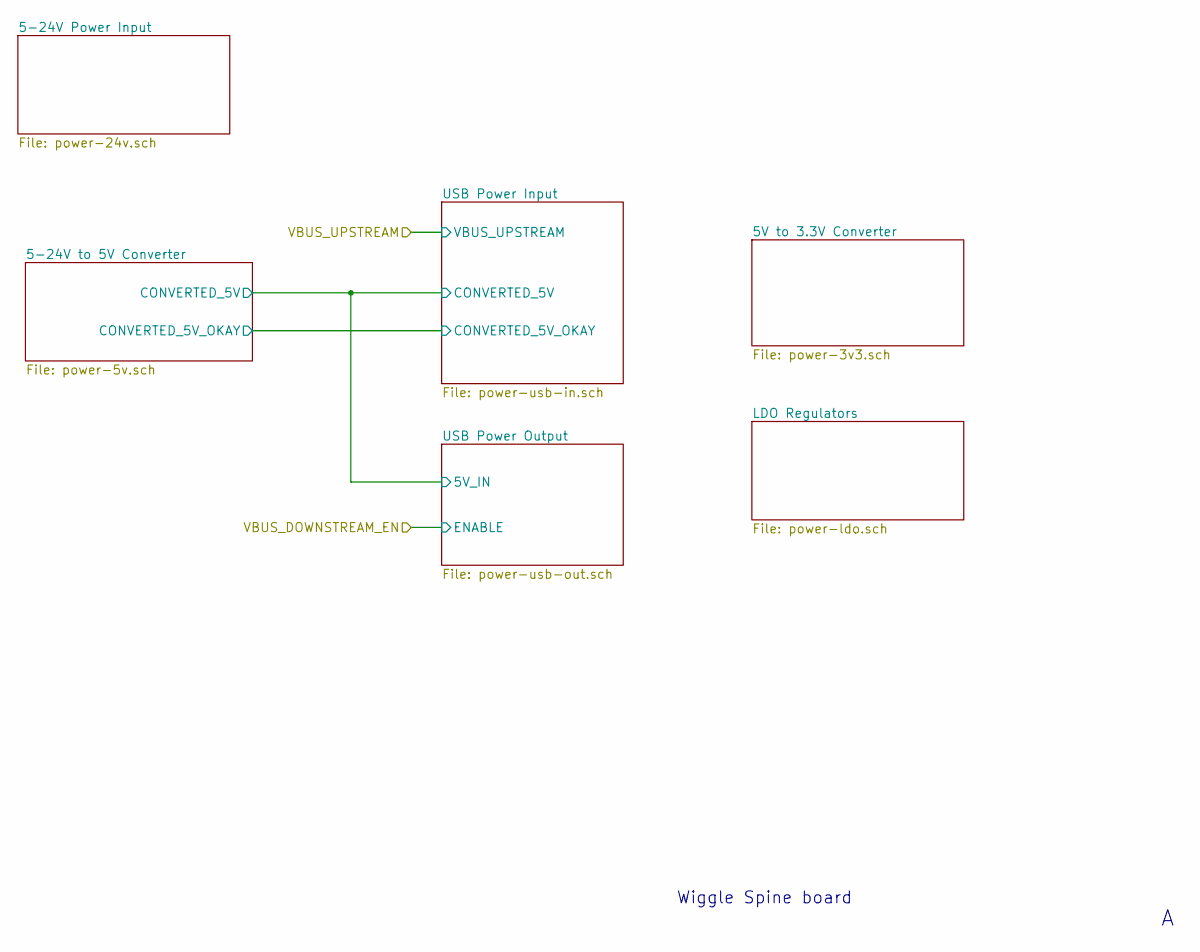
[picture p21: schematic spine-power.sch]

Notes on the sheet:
Wiggle Spine board

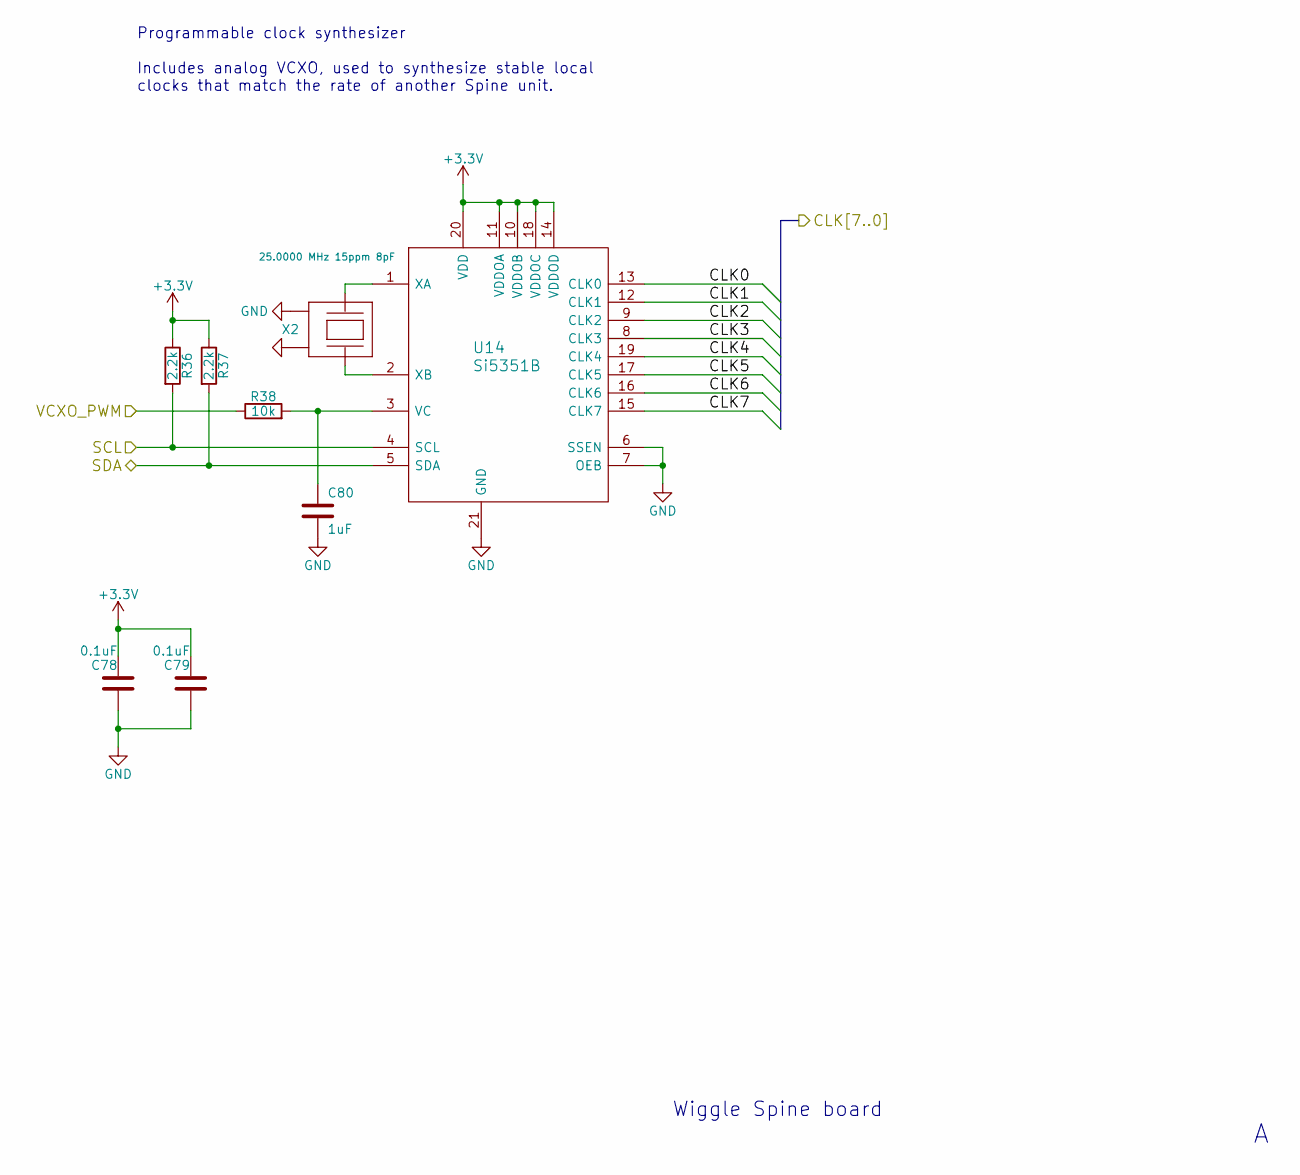
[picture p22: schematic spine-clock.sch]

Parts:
C78, C79: 0.1uF; C_0805
C80: 1uF; C_0805
R36, R37: 2.2k; R_0805
R38: 10k; R_0805
U14: Si5351B; QFN-20-1EP_4x4mm_Pitch0.5mm
X2: 25.0000 MHz 15ppm 8pF; crystal_FA238-TSX3225

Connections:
/Clock Source/CLK0: U14.13 (CLK0); also elsewhere on the board
/Clock Source/CLK1: U14.12 (CLK1); also elsewhere on the board
/Clock Source/CLK2: U14.9 (CLK2); also elsewhere on the board
/Clock Source/CLK3: U14.8 (CLK3); also elsewhere on the board
/Clock Source/CLK4: U14.19 (CLK4); also elsewhere on the board
/Clock Source/CLK5: U14.17 (CLK5); also elsewhere on the board
/Clock Source/CLK6: U14.16 (CLK6); also elsewhere on the board
/Clock Source/CLK7: U14.15 (CLK7); also elsewhere on the board
/Clock Source/VCXO_PWM: R38.1; also elsewhere on the board
/FPGA/CLK_SCL: R36.2, U14.4 (SCL); also elsewhere on the board
/FPGA/CLK_SDA: R37.2, U14.5 (SDA); also elsewhere on the board
GND: C78.1, C79.1, C80.2, U14.6 (SSEN), U14.7 (OEB), U14.21 (GND), X2.2, X2.4; also elsewhere on the board
unnamed: C80.1, R38.2, U14.3 (VC)
unnamed: U14.1 (XA), X2.1
unnamed: U14.2 (XB), X2.3

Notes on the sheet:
Programmable clock synthesizer Includes analog VCXO, used to synthesize stable local clocks that match the rate of another Spine unit.
Wiggle Spine board

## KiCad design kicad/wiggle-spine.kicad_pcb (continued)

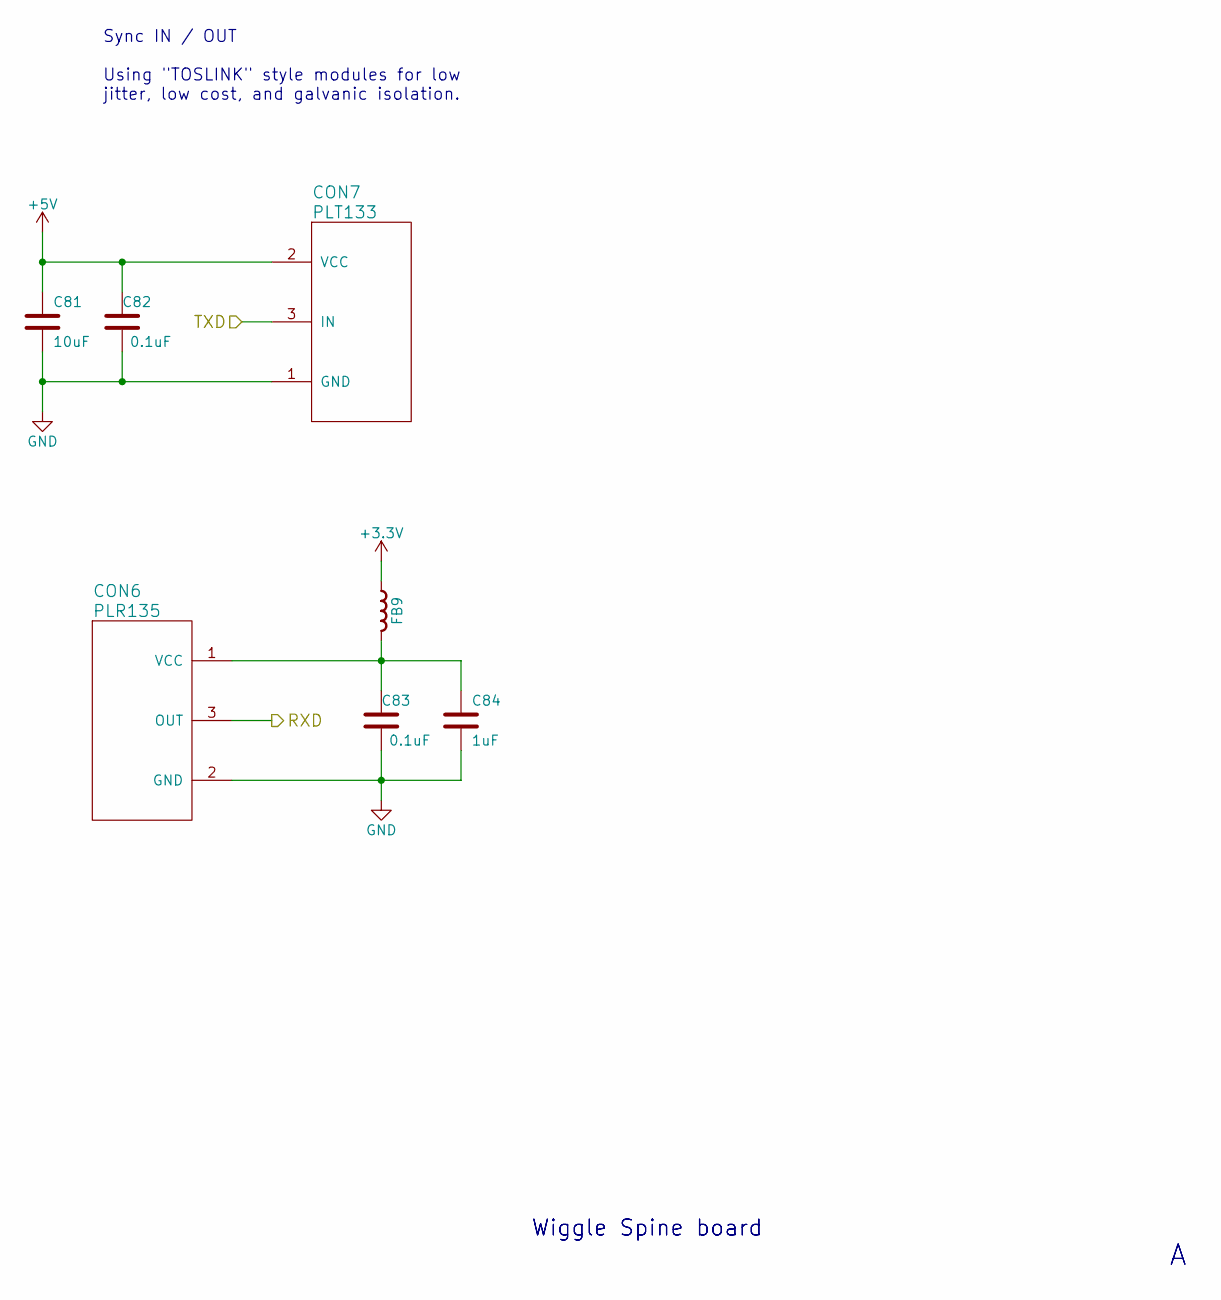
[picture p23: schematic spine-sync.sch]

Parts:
C81: 10uF; C_1206
C82, C83: 0.1uF; C_0805
C84: 1uF; C_0805
CON6: PLR135; Everlight-PLR135-T8
CON7: PLT133; Everlight-PLT133-T6A
FB9: Ferrite bead; R_0805

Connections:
+5V: C81.1, C82.2, CON7.2 (VCC); also elsewhere on the board
/FPGA/SYNC_TXD: CON7.3 (IN); also elsewhere on the board
/Sync In/Out/RXD: CON6.3 (OUT); also elsewhere on the board
GND: C81.2, C82.1, C83.1, C84.2, CON6.2 (GND), CON7.1 (GND); also elsewhere on the board
unnamed: C83.2, C84.1, CON6.1 (VCC), FB9.2

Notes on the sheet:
Sync IN / OUT Using "TOSLINK" style modules for low jitter, low cost, and galvanic isolation.
Wiggle Spine board

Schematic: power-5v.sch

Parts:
C43, C44, C50, C51: 22uF; c_elec_6.3x7.7
C45, C46, C52: 10uF; C_1206
C47: 1uF; C_0805
C48: 0.1uF; C_0805
C49: 100pF; C_0805
D6: BAT54 2x common cathode; SOT-23
L1: 22uH; Neosid_Inductor_SM-NE127
R23, R27: 100k; R_0805
R24: 150; R_0805
R25: 27k 1%; R_0805
R26: 5.1k 1%; R_0805
U7: RT8299A; SOIC-8-1EP_3.9x4.9mm_Pitch1.27mm

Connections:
+24V: C43.1, C44.1, C45.1, C46.1, R23.1, U7.2 (VIN); also elsewhere on the board
/Power/5-24V to 5V Converter/CONVERTED_5V_OKAY: R27.1, U7.7 (PGOOD); also elsewhere on the board
/Power/USB Power Output/5V_IN: C50.1, C51.1, C52.1, D6.1 (A), D6.2 (A), L1.2, R25.2, R27.2; also elsewhere on the board
GND: C43.2, C44.2, C45.2, C46.2, C47.2, C49.1, C50.2, C51.2, C52.2, R26.1, U7.4 (GND), U7.9 (GND); also elsewhere on the board
unnamed: C47.1, U7.8 (VCC)
unnamed: C48.1, L1.1, R24.2, U7.3 (SW)
unnamed: C48.2, D6.3 (K), U7.1 (BOOT)
unnamed: C49.2, R24.1
unnamed: R23.2, U7.6 (EN)
unnamed: R25.1, R26.2, U7.5 (FB)

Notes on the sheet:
Open drain output
Bootstrap assistance for Vin < 5.5
Wiggle Spine board
High efficiency DC-DC converter, 5V at 3A from 5-24V DC. This 5V rail is shared by the USB output (up to 2A), the modules (100mA each), and all FPGA and USB controller power rails.

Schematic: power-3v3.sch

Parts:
C53, C59, C60: 22uF; c_elec_6.3x7.7
C54, C55, C61: 10uF; C_1206
C56: 1uF; C_0805
C57: 0.1uF; C_0805
C58: 100pF; C_0805
D7: BAT54 2x common cathode; SOT-23
L2: 22uH; Neosid_Inductor_SM-NE127
R28: 150; R_0805
R29: 16k 1%; R_0805
R30: 5.1k 1%; R_0805
U8: RT8299A; SOIC-8-1EP_3.9x4.9mm_Pitch1.27mm

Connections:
+5V: C53.1, C54.1, C55.1, D7.1 (A), D7.2 (A), U8.2 (VIN), U8.6 (EN); also elsewhere on the board
GND: C53.2, C54.2, C55.2, C56.2, C58.1, C59.2, C60.2, C61.2, R30.1, U8.4 (GND), U8.9 (GND); also elsewhere on the board
unnamed: C56.1, U8.8 (VCC)
unnamed: C57.1, L2.1, R28.2, U8.3 (SW)
unnamed: C57.2, D7.3 (K), U8.1 (BOOT)
unnamed: C58.2, R28.1
unnamed: R29.1, R30.2, U8.5 (FB)

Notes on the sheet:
Bootstrap assistance diode; see RT8299A data sheet
Wiggle Spine board
High efficiency DC-DC converter, 3.3V at 3A

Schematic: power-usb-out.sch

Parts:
C62: 1uF; C_0805
C63, C64: 0.1uF; C_0805
CON3: USB-A; USB_A_Vertical
F2: 2A PTC; R_1812
FB5, FB6: Ferrite bead; R_0805
R31, R32: 100k; R_0805
U9: SiP32408; TDFN4

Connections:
/FPGA/VBUS_DOWNSTREAM_EN: R31.1, U9.3 (EN); also elsewhere on the board
/Power/USB Power Output/5V_IN: C62.1, R31.2, U9.1 (IN); also elsewhere on the board
Earth: CON3.5 (shield); also elsewhere on the board
GND: C62.2, C63.1, C64.1, FB6.1, R32.2, U9.2 (GND), U9.5 (GND); also elsewhere on the board
unnamed: C63.2, F2.1, R32.1, U9.4 (OUT)
unnamed: C64.2, F2.2, FB5.1
unnamed: CON3.1 (VCC), FB5.2
unnamed: CON3.2 (D-), CON3.3 (D+)
unnamed: CON3.4 (GND), FB6.2

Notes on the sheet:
Not the main +5V rail; this is intended to draw power from the DC-DC converter only, not the USB-B input.
USB power output, 5V 2A. Intended to power a small computer, like the Raspberry Pi 2. Optional hardware watchdog timer, implemented in the FPGA.
Wiggle Spine board

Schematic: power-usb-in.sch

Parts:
C65, C68, C69: 0.1uF; C_0805
C66, C67: 1uF; C_0805
C70, C71: 10uF; C_1206
D8: 8.5VWM; SOT-23
Q2: 2N7002P; SOT-23
R33: 100k; R_0805
R34: 2.2k; R_0805
U10, U11: SiP32408; TDFN4

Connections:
+5V: C68.2, C69.2, C70.1, C71.1, D8.1 (K), D8.2 (K), U10.4 (OUT), U11.4 (OUT); also elsewhere on the board
/Power/5-24V to 5V Converter/CONVERTED_5V_OKAY: Q2.1 (G), U11.3 (EN); also elsewhere on the board
/Power/USB Power Output/5V_IN: C67.1, U11.1 (IN); also elsewhere on the board
/Power/VBUS_UPSTREAM: C66.1, R33.1, U10.1 (IN); also elsewhere on the board
GND: C65.1, C66.2, C67.2, C68.1, C69.1, C70.2, C71.2, D8.3 (A), Q2.2 (S), U10.2 (GND), U10.5 (GND), U11.2 (GND), U11.5 (GND); also elsewhere on the board
unnamed: C65.2, R33.2, R34.1, U10.3 (EN)
unnamed: Q2.3 (D), R34.2

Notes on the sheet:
When USB power is available, route it to the +5V rail (with reverse current protection) When/if external 5V becomes available, switch to it softly, then draw no power from upstream USB.
(High-Z logic input)
Wiggle Spine board
Transient clamping

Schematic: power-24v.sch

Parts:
C72: 0.1uF; C_0805
C73: 1uF; C_0805
CON4: 2.5mm 5-24V 5A; BARREL_JACK
CON5: 5-24V 16A; TerminalBlock_Pheonix_PT-3.5mm_4pol
D9: 8.5VWM; SOT-23
FB7, FB8: Ferrite bead; R_0805
Q3: AOD4189; TO-252-2Lead
R35: 100k; R_0805

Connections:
+24V: C73.1, D9.1 (K), D9.2 (K), Q3.3 (S); also elsewhere on the board
/Power/5-24V Power Input/POWER_IN: C72.2, CON4.1, CON5.1, CON5.2, Q3.2 (D)
Earth: FB7.2; also elsewhere on the board
GND: FB8.2; also elsewhere on the board
GNDPWR: C72.1, C73.2, CON4.2, CON4.3, CON5.3, CON5.4, FB7.1, FB8.1, R35.2; also elsewhere on the board
unnamed: D9.3 (A), Q3.1 (G), R35.1

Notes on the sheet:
Reverse polarity protection
Power input options
High power return, from modules
Wiggle Spine board
Main (digital) ground net
Shield ground

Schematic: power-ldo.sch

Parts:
C74, C76: 0.1uF; C_0805
C75, C77: 1uF; C_0805
U12: TCR2EF25; SOT-23-5
U13: TCR2EF12; SOT-23-5

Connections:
+1V2: C77.1, U13.5 (Vout); also elsewhere on the board
+2V5: C75.1, C76.2, U12.5 (Vout), U13.1 (Vin), U13.3 (CONTROL); also elsewhere on the board
GND: C74.1, C75.2, C76.1, C77.2, U12.2 (GND), U13.2 (GND); also elsewhere on the board

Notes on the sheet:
Low voltage / low current LDO regulators for FPGA
1.2v = FPGA core voltage
2.5v = FPGA NVCM programming voltage (Some circuits approximate this with a diode drop from 3.3v, but that's pretty dirty and these LDOs are about as cheap as a diode.)
Wiggle Spine board

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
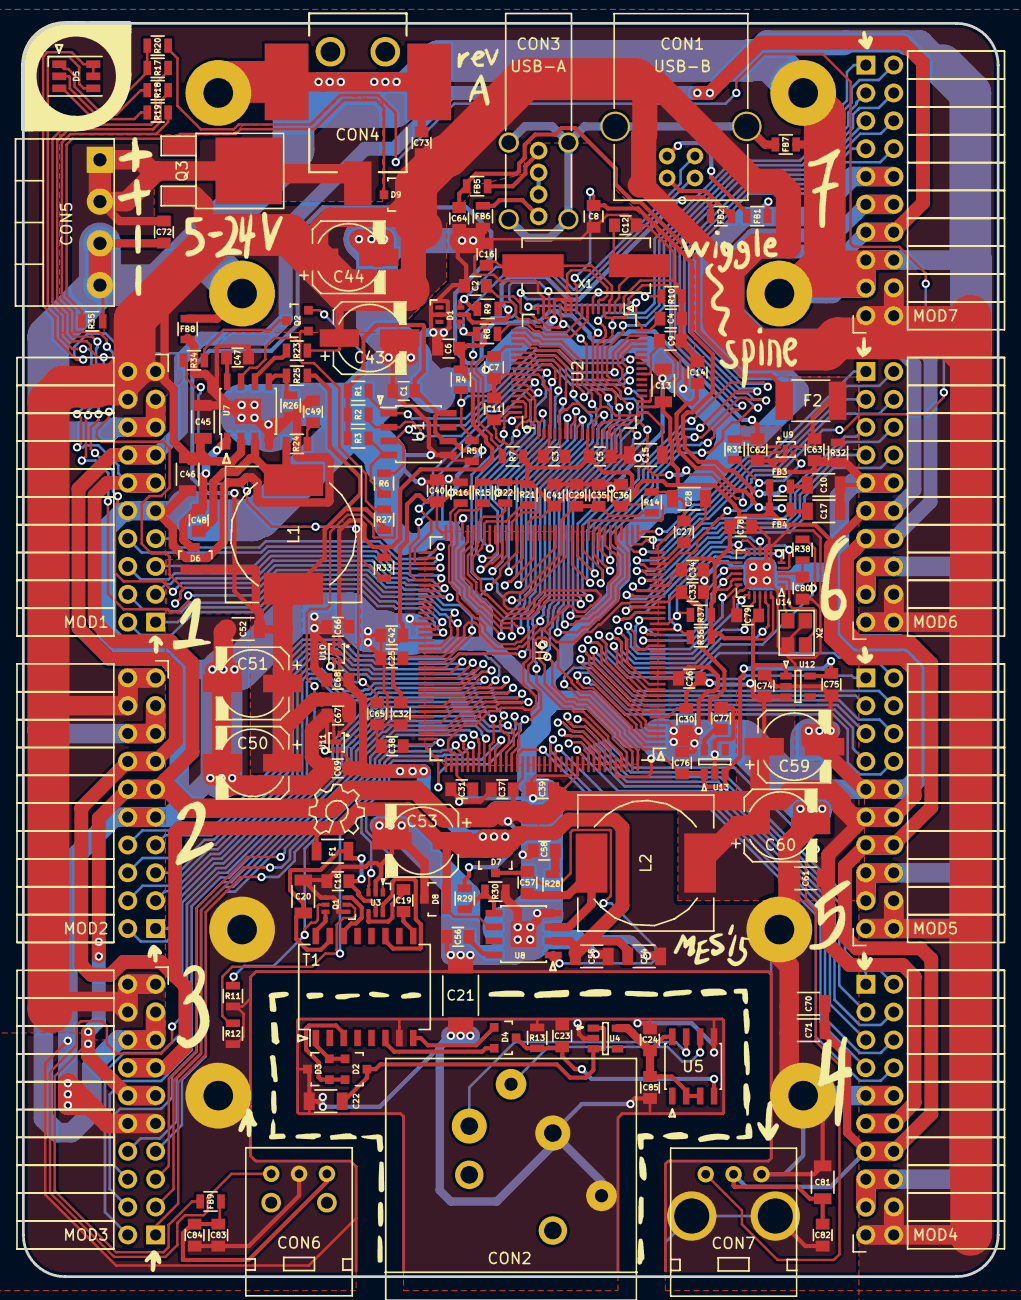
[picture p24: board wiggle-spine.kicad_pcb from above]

Board: 2 copper layers, 88.9 x 114.3 mm, 179 parts (0 on the bottom side), 172 nets.

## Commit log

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2015-11-08 Untested draft of the DMX isolator subcircuit
    [spine-dmx512.sch, spine-fpga.sch, spine-usb.sch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]
2015-11-08 Get the BOM started
    [spine-dmx512.sch, spine-fpga.sch, spine-usb.sch]
2015-11-08 Fuss with the USB
    [spine-usb.sch]
2015-11-09 USB port: ESD, crystal, eeprom
    [spine-dmx512.sch, spine-fpga.sch, spine-usb.sch]
2015-11-09 More schematic work: module ports and USB
    [spine-dmx512.sch, spine-fpga.sch, spine-modules.sch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]
2015-11-09 Getting the FPGA set up
    [spine-dmx512.sch, spine-fpga.sch, spine-modules.sch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]
2015-11-10 Pick better capacitors :)
    [spine-dmx512.sch, spine-fpga.sch, spine-modules.sch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]
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2015-11-17 Early power management work
    [spine-dmx512.sch, spine-fpga.sch, spine-modules.sch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]
2015-11-18 Split up the power schematic
    [power-24v.sch, power-3v3.sch, power-5v.sch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]
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2015-11-18 Power management and such
    [power-24v.sch, power-3v3.sch, power-5v.sch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]
2015-11-19 Clock generator, sync connectors, title blocks
    [power-24v.sch, power-3v3.sch, power-5v.sch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]
2015-11-19 Start keeping BOM and schematic plots in git?
    [wiggle-spine.csv]
2015-11-19 Adding prototype materials for reference
    [wiggle-spine-digikey-1.csv]
2015-11-29 Fixes for shield grounds and module numbering
    [power-24v.sch, power-3v3.sch, power-5v.sch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]
2015-11-29 Schematic footprint and refdes work
    [power-24v.sch, power-3v3.sch, power-5v.sch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]
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2015-11-30 Real footprint for DMX
    [wiggle-spine.kicad_pcb]
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2015-11-30 Some more component placement
    [wiggle-spine.kicad_pcb]
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2015-11-30 More footprint fixes, and pin-1 dots
    [wiggle-spine.kicad_pcb]
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2015-12-01 Component clustering around top and bottom I/O ports
    [wiggle-spine.kicad_pcb]
2015-12-01 Try 2.7" width
    Probably too narrow to fit the DCDCs, but it looks nice doesn't it.
    [wiggle-spine.kicad_pcb]
2015-12-01 More component packing
    If this routing is at all realistic, maybe 2.7" works after all. Haven't placed the DCDCs yet, but I think they'll fit.
    [wiggle-spine.kicad_pcb]
2015-12-01 Fix MOD pinouts, and layout for 2.7x5.2in
    [wiggle-spine.kicad_pcb]
2015-12-01 Adjust holes, pmod spacing, rounded corners
    [wiggle-spine.kicad_pcb]
2015-12-01 Ordered LEDs to test
    [wiggle-spine-digikey-2.csv]
2015-12-01 Simpler indicator LED strategy
    [power-24v.sch, power-3v3.sch, power-5v.sch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]
2015-12-01 Save room for a Wiggleport logo
    [wiggle-spine.kicad_pcb]
2015-12-02 Fix some 6-pin packages
    I had several of these mislabeled as SOT23-6, but there are no SOT23-6 parts here. The LDOs are SOT23-5, and the others (TVS diode array and inverters) are in the smaller SC-88 package.
    [power-24v.sch, power-3v3.sch, power-5v.sch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]
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2015-12-02 Separated ground planes, starting on design rules
    [power-24v.sch, power-ldo.sch, power-usb-in.sch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]
2015-12-02 Some 24V power routing
    [wiggle-spine.kicad_pcb]
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2015-12-03 Switch to a ferrite bead with 6A current rating
    [power-24v.sch, power-usb-out.sch, spine-sync.sch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]
2015-12-04 Bulk adjust for 9mil trace / 10mil space
    This is a compromise between the QFP packages and the Othermill with a 10 mil endmill :)
    [wiggle-spine.kicad_pcb]
2015-12-04 Some routing, especially on the isolated DMX side
    [wiggle-spine.kicad_pcb]
2015-12-05 More routing, and QFN footprint tweaks
    [wiggle-spine.kicad_pcb]
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2015-12-06 More swapping and rerouting on the FPGA
    [power-24v.sch, power-3v3.sch, power-5v.sch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]
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2015-12-07 Fighting with kicad, not sure if the keepouts are working
    [wiggle-spine.kicad_pcb]
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2015-12-07 Yikes, fix GNDPWR/GND overlap
    Not sure why the last DRC missed this. Zones still fighting with each other when they overlap?
    [wiggle-spine.kicad_pcb]
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2015-12-07 Fix Edge.Cuts layer
    [wiggle-spine.kicad_pcb]
2015-12-07 Landscape orientation
    Trying to work around a possible otherplan issue
    [wiggle-spine.kicad_pcb]
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2015-12-07 Move Sync TX trace further from DMX port
    [wiggle-spine-B.Cu.gbr, wiggle-spine-B.Mask.gbr, wiggle-spine-B.SilkS.gbr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]
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2015-12-17 Test 512 slots of DMX
    Having some issues when removing DEBUG. Not sure if it's my fault or the synthesizer atm.
2015-12-19 First round of DMX isolator simplifications
    - Removed RC filters on gate drive; they aren't accurate enough to prevent the FPGA from destroying the FETs with bad drive frequencies or duty cycles. I'm planning on spec'ing a polyfuse to protect this circuit instead. Leaving in the DC blocking cap on the signal side, since the inverter output impedance is high enough it probably wouldn't reliably trigger a polyfuse before breaking.
    - Removed fancypants schmitt trigger nonsense in the demodulator. This was just oscillating and wasn't working like it did in simulation at all, but it turns out we can just use the '485 driver input directly. The peak detector output is plenty strong with a 6 MHz c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
    [power-3v3.sch, power-5v.sch, power-ldo.sch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]
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2015-12-20 More simplification and BOM optimization
    Thanks for the hints on the ST485 and dual-FETs, @mikelectricstuf!
    [power-24v.sch, power-3v3.sch, power-5v.sch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]
2015-12-21 BOM tweaks, starting DC/DC fixes
    VCC is not active until EN goes high, so EN must be
    connected to VIN via the 100k resistor. Internal resistance
    is 5k to a 3V zener.
    [power-24v.sch, power-3v3.sch, power-5v.sch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]
2015-12-22 BOM cleanup
    Especially fix the confusing and mostly incorrect Mfg/Mfr stuff that I inherited from somewhere.
    [power-24v.sch, power-3v3.sch, power-5v.sch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]
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2015-12-22 About 50% dimmer blue LED when FPGA is unconfigured
    This seems a good compromise between visibility while debugging and unobtrusiveness during normal operation.
    [power-24v.sch, power-3v3.sch, power-5v.sch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]
2015-12-23 Schematics stabilizing for next proto, starting PCB updates
    [power-24v.sch, power-3v3.sch, power-5v.sch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]
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2015-12-23 Found room for the sync plugs and LED
    [wiggle-spine.kicad_pcb]
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2015-12-23 Placement draft with everything other than SMPS on board
    [wiggle-spine.kicad_pcb]
2015-12-23 Off-board SMPS placement
    Much happier with the high current paths this time
    [wiggle-spine.kicad_pcb]
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2015-12-23 Flip DMX TX to improve 5V locality
    [wiggle-spine.kicad_pcb]
2015-12-23 Trying a dashed silkscreen outline for the isolation barrier
    [wiggle-spine.kicad_pcb]
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2015-12-24 Hand edit to duplicate gap boundaries on bottom layer
    [wiggle-spine.kicad_pcb]
2015-12-24 Via stitching and net fixes for DMXGND
    [wiggle-spine.kicad_pcb]
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2015-12-25 DRC tweak, 0.2mm clearance
    This is the largest we can get away with, due to the TDFN4 footprint. It's a litlte over 7 mils, which is over oshpark's 6 mil minimum.
    [wiggle-spine.kicad_pcb]
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2015-12-25 Feeling better about GNDPWR and GND along the edges
    [wiggle-spine.kicad_pcb]
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2015-12-25 More power routing, making room for the 5V vertical
    [wiggle-spine.kicad_pcb]
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2015-12-26 Redo component annotation
    Noticed the module numbers were wrong after the last reannotation, so this seemed like a good time to reannotate again.
    [power-24v.sch, power-3v3.sch, power-5v.sch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]
2015-12-26 Route some port GPIOs
    but let's not get too carried away before placing everything...
    [wiggle-spine.kicad_pcb]
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2015-12-27 More power and signal routing, 5V switches mostly placed
    [wiggle-spine.kicad_pcb]
2015-12-27 More work on the loops around the 24V dcdc
    [wiggle-spine.kicad_pcb]
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2015-12-28 Think everything fits under U2 that needs to
    [wiggle-spine.kicad_pcb]
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2015-12-29 Ripup movable FPGA traces, route the few immovable ones
    [power-24v.sch, power-3v3.sch, power-5v.sch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]
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2015-12-30 Capacitor silkscreen fix
    [wiggle-spine.kicad_pcb]
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2015-12-30 Silk-in-pad fixes spotted by @oresk
    [wiggle-spine.kicad_pcb]
2015-12-30 Gerber format and silkscreen fixes
    [wiggle-spine-B.Cu.gbl, wiggle-spine-B.Mask.gbs, wiggle-spine-B.SilkS.gbr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]
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2015-12-31 Rotate board
    This seems to be the easiest way to keep the text orientation as I'd like it, and the board fits this way now
    [wiggle-spine.kicad_pcb]
2015-12-31 Remove heavy dashed border, to be replaced with a sketched version
    [wiggle-spine.kicad_pcb]
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2015-12-31 Fix overlap with "DMX OUT" label
    [wiggle-spine-B.Cu.gbl, wiggle-spine-B.Mask.gbs, wiggle-spine-B.SilkS.gbo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]
2015-12-31 Fix stray reference on front silk from OSHW logo
    [wiggle-spine-B.Cu.gbl, wiggle-spine-B.Mask.gbs, wiggle-spine-B.SilkS.gbo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]
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2015-12-31 Ordered new parts added in Wiggle Spine A
    [wiggle-spine-digikey-3.csv]
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2016-01-11 Replace TVS diode D1
    Previous part from NXP is going end-of-life, new part should be a drop-in replacement from Diodes Inc.
    [power-3v3.sch, power-5v.sch, power-ldo.sch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]
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2016-02-07 A few photos to document the board build
    [wiggle-spine-digikey-1.csv, wiggle-spine-digikey-2.csv, wiggle-spine-digikey-3.csv]
